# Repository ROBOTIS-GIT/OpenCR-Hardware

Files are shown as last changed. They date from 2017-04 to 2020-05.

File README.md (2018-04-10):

# OpenCR: Open Source Control Module for ROS
OpenCR (Open-source Control Module for ROS) is developed for ROS embedded systems to provide completely open-source hardware and software. 



# OpenCR-Hardware
Everything about the board; Schematics, PCB Gerber, BOM and the firmware source code for the TurtleBot3 and OP3 are free to distribute under open-source licenses for users and the ROS community. The STM32F7 series chip inside the OpenCR1.0 board is based on a very powerful ARM Cortex-M7 with floating point unit. The development environment for OpenCR1.0 is wide open from Arduino IDE and Scratch for young students to traditional firmware development for the expert.

## ROBOTIS e-Manual for OpenCR
- [ROBOTIS e-Manual for OpenCR](http://emanual.robotis.com/docs/en/parts/controller/opencr10/)

## Open Source related to OpenCR
- [OpenCR](https://github.com/ROBOTIS-GIT/OpenCR)
- [OpenCR-Hardware](https://github.com/ROBOTIS-GIT/OpenCR-Hardware)
- [OpenCM 9.04](https://github.com/ROBOTIS-GIT/OpenCM9.04)
- [dynamixel_sdk](https://github.com/ROBOTIS-GIT/DynamixelSDK)
- [dynamixel_workbench](https://github.com/ROBOTIS-GIT/dynamixel-workbench)
- [turtlebot3](https://github.com/ROBOTIS-GIT/turtlebot3)
- [open_manipulator](https://github.com/ROBOTIS-GIT/open_manipulator)
- [robotis_op3](https://github.com/ROBOTIS-GIT/ROBOTIS-OP3)

## Documents and Videos related to OpenCR
- [ROBOTIS e-Manual for OpenCR](http://emanual.robotis.com/docs/en/parts/controller/opencr10/)
- [ROBOTIS e-Manual for OpenCM 9.04](http://emanual.robotis.com/docs/en/parts/controller/opencm904/)
- [ROBOTIS e-Manual for OpenCM 485 Expansion Board](http://emanual.robotis.com/docs/en/parts/controller/opencm485exp/)
- [ROBOTIS e-Manual for Dynamixel SDK](http://emanual.robotis.com/docs/en/software/dynamixel/dynamixel_sdk/overview/)
- [ROBOTIS e-Manual for Dynamixel Workbench](http://emanual.robotis.com/docs/en/software/dynamixel/dynamixel_workbench/)
- [ROBOTIS e-Manual for TurtleBot3](http://turtlebot3.robotis.com/)
- [ROBOTIS e-Manual for OpenManipulator](http://emanual.robotis.com/docs/en/platform/openmanipulator/)
- [ROBOTIS e-Manual for ROBOTIS OP3](http://emanual.robotis.com/docs/en/platform/op3/introduction/)
- [Videos for OpenCR](https://www.youtube.com/playlist?list=PLRG6WP3c31_VTd-u90LVXaT1B8NMjCSoj)

## Tools for Hardware of OpenCR
- Schematic
  - OrCAD Capture 16.6

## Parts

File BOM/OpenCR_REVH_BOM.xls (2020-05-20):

BoardName | OpenCR
REV | H
Part Name | Reference | Quantity
C1608-1uF-16V | C2,C4,C5,C11,C70,C74,C100,C102,C103,C104,C105 | 11
C1608-NC | C6 | 1
C1005-0.1uF-35V | C7,C12,C13,C15,C16,C17,C18,C19,C20,C23,C24,C25,C26,C27,C28,C29,C30,C31,C32,C33,C35,C37,C44,C45,C46,C47,C51,C52,C55,C56,C61,C62,C66,C67,C71,C75,C79,C80,C81,C83,C84,C90,C94,C95,C96,C97,C99,C101,C106,C107,C108,C109,C110,C111,C112 | 55
C2012-4.7uF-16V | C14,C50,C69 | 3
C3216-10uF-25V | C21,C43,C59,C63,C22,C42,C48,C77 | 8
C1005-100pF-25V | C49,C57,C85 | 3
C1005-10nF-25V | C53 | 1
C1608-2.2uF-10V | C54,C82 | 2
C1005-9pF-25V | C58,C60 | 2
C3216-1uF-50V | C64,C87,C93,C98 | 4
C1005-8pF-25V | C65,C68 | 2
C2012-220nF-50V | C72 | 1
C2012-4.7nF/100V | C78 | 1
C1005-22nF-25V | C86 | 1
C1005-8.2nF-16V | C88 | 1
C1005-150pF-50V | C89 | 1
C1005-47pF-50V | C91 | 1
LED1608-ORANGE | D1,D2,D11 | 3
LED1608-RED | D3 | 1
LED1608-GREEN | D4,D5,D6,D7,D12 | 5
SS14-T3 (1N5819 SMA) | D9,D10,D22,D23 | 4
SK24 | D13 | 1
SK34C | D14,D17,D18,D19,D20,D21 | 6
SD24C | D15 | 1
SK56B | D16 | 1
BXJ(D10/L10), 470uF, 25V | EC1,EC3 | 2
BXJ(D5/L5.3), 22uF, 25V | EC2,EC4,EC5 | 3
BXJ(D8/L10), 68uF, 50V | EC6,EC7 | 2
BLM18PG121SN1 | FB1,FB4,FB6 | 3
FCM1608KF-601T03 | FB3,FB5 | 2
MF-MSMF200-2 | F1 | 1
Fuse_154010_DR(125V10A)_SMD | F2 | 1
FEMALE-10_2.54 | JP1 | 1
FEMALE-8_2.54 | JP2,JP3 | 2
FEMALE-6_2.54 | JP4 | 1
HEADER 5X2 1.27MM | J1 | 1
HEADER 10X2 2.54MM | J3 | 1
20010WS-02 | J5 | 1
20010WS-04 | J6,J8,J25 | 3
Molex 5267-02 | J7 | 1
SMW250-02 | J9,J10 | 2
ZX62D-B-5P8 | J11 | 1
DC JACK | J12 | 1
HEADER 1X2 2.0MM | J13 | 1
DEANS CONNECTOR (MALE) | J14 | 1
B3B-EH-A | J15,J16,J17 | 3
B4B-EH-A | J18,J19,J20 | 3
HEADER 3X2 2.54MM | J21 | 1
HEADER 5X2 2.0MM | J22,J24 | 2
Molex 53047-0210 | J23 | 1
BTN-0327 | LS1 | 1
33uH, 4A, | L1 | 1
XAL6060-472MEB | L2 | 1
CSD17577Q3A | Q5,Q7 | 2
CSD17302Q5A | Q6 | 1
CSD18537NQ5A | Q8 | 1
IRF4905SPbF | Q9 | 1
KRC106S | Q10,Q13,Q14 | 3
MMBT2222A/SOT | Q29 | 1
MMBT2907A/SOT | Q30 | 1
QM3016AD | Q31 | 1
R1005-470R | R1,R2,R3,R4,R5,R6,R7 | 7
R1005-10K | R8,R9,R10,R11,R36,R42,R50,R51,R55,R56,R57,R62,R64,R65,R66,R71,R73,R77,R78,R94,R97,R103,R104,R118,R120,R121,R124,R131,R132,R133,R135,R159,R162,R165,R167,R168,R170,R171,R173,R174,R176 | 41
R1005-10R | R12,R13,R14,R15,R16,R17,R18,R19,R20,R21,R22,R23,R24,R25,R26,R27,R28,R29 | 18
0.5 | R163,R164,R177,R178 | 4
R1608-0R | R34,R111,R119 | 3
R1005-22R | R37,R38,R160,R161 | 4
R1005-0R | R41,R44,R47,R48,R49,R52,R53,R54,R61,R63,R68,R70,R72,R91,R98,R102,R105,R108,R109 | 19
R1005-47K | R43,R134,R136,R137 | 4
R1005-620R | R45 | 1
R1005-330R | R46 | 1
R6432-0.01R | R58 | 1
R1608-100R | R59,R60 | 2
R1005-NC | R67,R69,R100,R106,R166,R169,R172,R175 | 8
R3216-120R | R74 | 1
R1608-10R | R75,R76,R110 | 3
R1005-10.5K | R90 | 1
R1005-2K | R92 | 1
R1005-100R | R93 | 1
R1005-2.7K | R95,R96,R179,R180 | 4
R1005-60.4R | R99,R101 | 2
R1005-63.4K | R112,R115,R117 | 3
R1608-10M | R113 | 1
R1608-93.1K | R116 | 1
R1005-5.36K | R122 | 1
R1608-280K | R126 | 1
R1608-20K | R127,R129 | 2
R1005-100K | R153,R154,R155,R156 | 4
R1005-22K | R157 | 1
SHK-02 | SW1 | 1
5MS1S12AM6QE | SW2 | 1
ST-1185S | SW3,SW4,SW5 | 3
DJTA-1101 | SW6 | 1
SM712 | U2,U12,U23 | 3
SQS401EN | U3 | 1
XL4005 | U4 | 1
STMPS2141STR | U5 | 1
STM32F746ZGT6 | U6 | 1
IL1117-5.0ET | U7,U14 | 2
ADM6713RAKS | U8 | 1
MPU-9250 | U9 | 1
AZ1117H-3_3TRG1 (SOT-223) | U10,U13 | 2
TJF1051T/3 | U11 | 1
EMIF02-USB03F2 | U16 | 1
LM5175PWPR | U17 | 1
LMV358IDGKR | U18 | 1
NC7WZ241K8X | U20 | 1
MAX3443ECSA+ | U21 | 1
NC7SZ08P5X | U22 | 1
A3906SESTR-T, QFN20 | U24,U25 | 2
X-Tal-32.768kHz_CM315 (CS-3215) | Y1 | 1
X-Tal-25MHz_SP8150E7 (SX-32) | Y2 | 1
R1608-47R | R181 | 1

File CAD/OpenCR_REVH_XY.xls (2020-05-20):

RefDes | PartDecal | Pins | Layer | Orient. | X | Y | SMD | Glued
C2 | ORC-CC1608 | 2 | Top | 180 | 83.42900067 | 68.56999933 | TRUE | FALSE
C4 | ORC-CC1608 | 2 | Top | 270 | 50.79999867 | 66.21099933 | TRUE | FALSE
C5 | ORC-CC1608 | 2 | Top | 270 | 52.399998 | 66.21099933 | TRUE | FALSE
C6 | ORC-CC1608 | 2 | Top | 180 | 50.31009867 | 63.308798 | TRUE | FALSE
C7 | ORC-CC1005 | 2 | Top | 90 | 98.05 | 62.4 | TRUE | FALSE
C11 | ORC-CC1608 | 2 | Bottom | 180 | 27.25 | 47.25 | TRUE | FALSE
C12 | ORC-CC1005 | 2 | Bottom | 0 | 27 | 48.75 | TRUE | FALSE
C13 | ORC-CC1005 | 2 | Bottom | 270 | 5.75 | 46.5 | TRUE | FALSE
C14 | ORC-CC2012 | 2 | Top | 180 | 94.4088 | 42.28989867 | TRUE | FALSE
C15 | ORC-CC1005 | 2 | Top | 180 | 101.108798 | 28.63989867 | TRUE | FALSE
C16 | ORC-CC1005 | 2 | Top | 180 | 96.80879933 | 28.58989867 | TRUE | FALSE
C17 | ORC-CC1005 | 2 | Top | 180 | 103.1087993 | 20.089898 | TRUE | FALSE
C18 | ORC-CC1005 | 2 | Top | 90 | 49.65 | 38 | TRUE | FALSE
C19 | ORC-CC1005 | 2 | Top | 270 | 51.71350067 | 40.825 | TRUE | FALSE
C20 | ORC-CC1005 | 2 | Top | 270 | 53.9135 | 40.8 | TRUE | FALSE
C21 | ORC-CC3216 | 2 | Top | 0 | 73.899998 | 15.29999867 | TRUE | FALSE
C22 | ORC-CC3216 | 2 | Top | 180 | 78.899998 | 15.29999867 | TRUE | FALSE
C23 | ORC-CC1005 | 2 | Top | 90 | 81.89999467 | 15.09999933 | TRUE | FALSE
C24 | ORC-CC1005 | 2 | Top | 270 | 61.75 | 14.75 | TRUE | FALSE
C25 | ORC-CC1005 | 2 | Top | 180 | 61.45879867 | 9.6 | TRUE | FALSE
C26 | ORC-CC1005 | 2 | Top | 0 | 67.499998 | 9.6 | TRUE | FALSE
C27 | ORC-CC1005 | 2 | Top | 180 | 53.83879867 | 9.499997333 | TRUE | FALSE
C28 | ORC-CC1005 | 2 | Top | 0 | 39.94149867 | 5.587998667 | TRUE | FALSE
C29 | ORC-CC1005 | 2 | Top | 180 | 31.3588 | 5.164898667 | TRUE | FALSE
C30 | ORC-CC1005 | 2 | Top | 0 | 50.99049867 | 5.524498667 | TRUE | FALSE
C31 | ORC-CC1005 | 2 | Top | 0 | 61.3588 | 5.5245 | TRUE | FALSE
C32 | ORC-CC1005 | 2 | Top | 0 | 75.0088 | 5.039898667 | TRUE | FALSE
C33 | ORC-CC1005 | 2 | Top | 0 | 88.14999733 | 5.499998 | TRUE | FALSE
C35 | ORC-CC1005 | 2 | Bottom | 0 | 8.5 | 64.75 | TRUE | FALSE
C37 | ORC-CC1005 | 2 | Bottom | 0 | 8.5 | 66 | TRUE | FALSE
C42 | ORC-CC3216 | 2 | Bottom | 180 | 58.95 | 53.9 | TRUE | FALSE
C43 | ORC-CC3216 | 2 | Bottom | 180 | 48.35879733 | 56.18989933 | TRUE | FALSE
C44 | ORC-CC1005 | 2 | Bottom | 0 | 58.29299867 | 55.81649867 | TRUE | FALSE
C45 | ORC-CC1005 | 2 | Bottom | 270 | 12.75 | 67.1 | TRUE | FALSE
C46 | ORC-CC1005 | 2 | Bottom | 270 | 75.14449867 | 51.62549867 | TRUE | FALSE
C47 | ORC-CC1005 | 2 | Bottom | 270 | 70.44549867 | 51.62549867 | TRUE | FALSE
C48 | ORC-CC3216 | 2 | Bottom | 90 | 5.3 | 64 | TRUE | FALSE
C49 | ORC-CC1005 | 2 | Bottom | 90 | 21.09119867 | 63.4601 | TRUE | FALSE
C50 | ORC-CC2012 | 2 | Bottom | 180 | 80.2 | 50.1388 | TRUE | FALSE
C51 | ORC-CC1005 | 2 | Bottom | 270 | 64.3088 | 52.63989867 | TRUE | FALSE
C52 | ORC-CC1005 | 2 | Bottom | 0 | 16 | 59.5 | TRUE | FALSE
C53 | ORC-CC1005 | 2 | Bottom | 180 | 20.59119867 | 64.7601 | TRUE | FALSE
C54 | ORC-CC1608 | 2 | Bottom | 180 | 80.2 | 48.4505 | TRUE | FALSE
C55 | ORC-CC1005 | 2 | Bottom | 270 | 5.5088 | 59.43989867 | TRUE | FALSE
C56 | ORC-CC1005 | 2 | Bottom | 270 | 65.2588 | 52.63989867 | TRUE | FALSE
C57 | ORC-CC1005 | 2 | Bottom | 90 | 21.1088 | 66.03989867 | TRUE | FALSE
C58 | ORC-CC1005 | 2 | Bottom | 270 | 67.442604 | 46.829798 | TRUE | FALSE
C59 | ORC-CC3216 | 2 | Bottom | 270 | 6.8588 | 52.93989867 | TRUE | FALSE
C60 | ORC-CC1005 | 2 | Bottom | 90 | 67.442604 | 44.72979733 | TRUE | FALSE
C61 | ORC-CC1005 | 2 | Bottom | 90 | 82.38349867 | 42.86249867 | TRUE | FALSE
C62 | ORC-CC1005 | 2 | Bottom | 0 | 64.85749867 | 41.52899867 | TRUE | FALSE
C63 | ORC-CC3216 | 2 | Bottom | 90 | 7.75 | 46.5 | TRUE | FALSE
C64 | ORC-CC3216 | 2 | Bottom | 90 | 24.6088 | 57.28989867 | TRUE | FALSE
C65 | ORC-CC1005 | 2 | Bottom | 270 | 67.4588 | 39.48989867 | TRUE | FALSE
C66 | ORC-CC1005 | 2 | Bottom | 270 | 33.25 | 34 | TRUE | FALSE
C67 | ORC-CC1005 | 2 | Bottom | 90 | 82.499998 | 37.55 | TRUE | FALSE
C68 | ORC-CC1005 | 2 | Bottom | 90 | 67.4588 | 37.389898 | TRUE | FALSE
C69 | ORC-CC2012 | 2 | Bottom | 0 | 65.6 | 36.45 | TRUE | FALSE
C70 | ORC-CC1608 | 2 | Bottom | 0 | 68.3088 | 34.68989867 | TRUE | FALSE
C71 | ORC-CC1005 | 2 | Bottom | 180 | 63.39999867 | 34.599998 | TRUE | FALSE
C72 | ORC-CC2012 | 2 | Bottom | 180 | 44.5 | 35.5 | TRUE | FALSE
C74 | ORC-CC1608 | 2 | Bottom | 0 | 68.3088 | 33.23829867 | TRUE | FALSE
C75 | ORC-CC1005 | 2 | Bottom | 180 | 63.39999867 | 33.19999867 | TRUE | FALSE
C77 | ORC-CC3216 | 2 | Bottom | 0 | 11.5 | 53.5 | TRUE | FALSE
C78 | ORC-CC2012 | 2 | Bottom | 270 | 97.950002 | 32.5 | TRUE | FALSE
C79 | ORC-CC1005 | 2 | Bottom | 180 | 75.90649867 | 30.79749867 | TRUE | FALSE
C80 | ORC-CC1005 | 2 | Bottom | 180 | 70.82649867 | 30.79749867 | TRUE | FALSE
C81 | ORC-CC1005 | 2 | Bottom | 180 | 65.91299867 | 30.79749867 | TRUE | FALSE
C82 | ORC-CC1608 | 2 | Bottom | 180 | 79.95 | 29.85 | TRUE | FALSE
C83 | ORC-CC1005 | 2 | Top | 270 | 35.75 | 31.5 | TRUE | FALSE
C84 | ORC-CC1005 | 2 | Bottom | 0 | 13.7 | 42.5 | TRUE | FALSE
C85 | ORC-CC1005 | 2 | Bottom | 0 | 45.5 | 29 | TRUE | FALSE
C86 | ORC-CC1005 | 2 | Bottom | 180 | 45.5 | 27.75 | TRUE | FALSE
C87 | ORC-CC3216 | 2 | Bottom | 270 | 23.5 | 26.5 | TRUE | FALSE
C88 | ORC-CC1005 | 2 | Bottom | 180 | 47.75 | 26.5 | TRUE | FALSE
C89 | ORC-CC1005 | 2 | Bottom | 180 | 45.5 | 25.5 | TRUE | FALSE
C90 | ORC-CC1005 | 2 | Bottom | 270 | 32.75 | 23 | TRUE | FALSE
C91 | ORC-CC1005 | 2 | Bottom | 0 | 35.25 | 23.25 | TRUE | FALSE
C93 | ORC-CC3216 | 2 | Top | 0 | 52.7 | 31.15 | TRUE | FALSE
C94 | ORC-CC1005 | 2 | Bottom | 90 | 77.35879733 | 17.239896 | TRUE | FALSE
C95 | ORC-CC1005 | 2 | Bottom | 90 | 71.875 | 15.75 | TRUE | FALSE
C96 | ORC-CC1005 | 2 | Bottom | 0 | 85.72499867 | 14.7 | TRUE | FALSE
C97 | ORC-CC1005 | 2 | Bottom | 0 | 36.14999733 | 11.949998 | TRUE | FALSE
C98 | ORC-CC3216 | 2 | Bottom | 180 | 40.424998 | 6.375 | TRUE | FALSE
C99 | ORC-CC1005 | 2 | Top | 180 | 15.1088 | 68.28989867 | TRUE | FALSE
C100 | ORC-CC1608 | 2 | Bottom | 0 | 64.8 | 48.6 | TRUE | FALSE
C101 | ORC-CC1005 | 2 | Bottom | 270 | 101 | 11.15 | TRUE | FALSE
C102 | ORC-CC1608 | 2 | Bottom | 0 | 97 | 64.25 | TRUE | FALSE
C103 | ORC-CC1608 | 2 | Bottom | 270 | 92 | 63.5 | TRUE | FALSE
C104 | ORC-CC1608 | 2 | Bottom | 180 | 94.25 | 64.25 | TRUE | FALSE
C105 | ORC-CC1608 | 2 | Bottom | 180 | 94.25 | 62.75 | TRUE | FALSE
C106 | ORC-CC1005 | 2 | Bottom | 180 | 100 | 52.25 | TRUE | FALSE
C107 | ORC-CC1005 | 2 | Top | 270 | 50.525 | 19.725 | TRUE | FALSE
C108 | ORC-CC1005 | 2 | Top | 270 | 50.525 | 21.6 | TRUE | FALSE
C109 | ORC-CC1005 | 2 | Top | 180 | 52.1 | 17.1 | TRUE | FALSE
C110 | ORC-CC1005 | 2 | Top | 270 | 60.025 | 19.725 | TRUE | FALSE
C111 | ORC-CC1005 | 2 | Top | 270 | 60.025 | 21.6 | TRUE | FALSE
C112 | ORC-CC1005 | 2 | Top | 90 | 60 | 17.8 | TRUE | FALSE
D1 | ORC-LED1608 | 2 | Top | 90 | 25.90879867 | 71.939898 | TRUE | FALSE
D2 | ORC-LED1608 | 2 | Top | 90 | 28.60879867 | 71.939898 | TRUE | FALSE
D3 | ORC-LED1608 | 2 | Top | 90 | 31.308798 | 71.939898 | TRUE | FALSE
D4 | ORC-LED1608 | 2 | Top | 90 | 34.008798 | 71.939898 | TRUE | FALSE
D5 | ORC-LED1608 | 2 | Top | 90 | 42.00879733 | 71.939898 | TRUE | FALSE
D6 | ORC-LED1608 | 2 | Top | 90 | 36.8088 | 71.939898 | TRUE | FALSE
D7 | ORC-LED1608 | 2 | Top | 90 | 39.50879933 | 71.939898 | TRUE | FALSE
D9 | ORC-SMA-SS14 | 2 | Top | 270 | 90.09999867 | 54.2 | TRUE | FALSE
D10 | ORC-SMA-SS14 | 2 | Top | 90 | 90.09999867 | 44.899998 | TRUE | FALSE
D11 | ORC-LED1608 | 2 | Top | 90 | 96.75879933 | 43.58989867 | TRUE | FALSE
D12 | ORC-LED1608 | 2 | Top | 90 | 99.45879867 | 43.58989867 | TRUE | FALSE
D13 | ORC-SMB-SS24 | 2 | Top | 270 | 25.5 | 22.5 | TRUE | FALSE
D14 | ORC-SMC-SS34 | 2 | Bottom | 90 | 21.75 | 34.5 | TRUE | FALSE
D15 | ORC-SOD323-TVS | 2 | Top | 0 | 57.4 | 5.65 | TRUE | FALSE
D16 | ORC-DO214AC | 2 | Top | 0 | 36.75 | 50.5 | TRUE | FALSE
D17 | ORC-SMC-SS34 | 2 | Bottom | 180 | 37.75 | 38.5 | TRUE | FALSE
D18 | ORC-SMC-SS34 | 2 | Bottom | 90 | 28.5 | 34.5 | TRUE | FALSE
D19 | ORC-SMC-SS34 | 2 | Bottom | 270 | 5 | 34 | TRUE | FALSE
D20 | ORC-SMC-SS34 | 2 | Bottom | 270 | 28.5 | 25.5 | TRUE | FALSE
D21 | ORC-SMC-SS34 | 2 | Bottom | 270 | 14.25 | 21 | TRUE | FALSE
D22 | ORC-SMA-SS14 | 2 | Bottom | 270 | 42.346 | 10.85 | TRUE | FALSE
D23 | ORC-SMA-SS14 | 2 | Bottom | 270 | 38.994 | 10.85 | TRUE | FALSE
EC1 | ORC-ACAP-D10XL0 | 2 | Top | 180 | 13.5 | 61 | TRUE | FALSE
EC2 | ORC-ACAP-D5XL5_3 | 2 | Top | 90 | 44 | 21.75 | TRUE | FALSE
EC4 | ORC-ACAP-D5XL5_3 | 2 | Top | 90 | 44 | 33.25 | TRUE | FALSE
EC5 | ORC-ACAP-D5XL5_3 | 2 | Top | 90 | 44 | 27.5 | TRUE | FALSE
EC6 | ORC-ACAP-D8XL0 | 2 | Top | 0 | 17 | 23.5 | TRUE | FALSE
EC7 | ORC-ACAP-D8XL0 | 2 | Top | 90 | 17 | 13 | TRUE | FALSE
EC8 | ORC-ACAP-D10XL0 | 2 | Top | 180 | 13.5 | 48.5 | TRUE | FALSE
F1 | ORC-FC4532 | 2 | Top | 270 | 94.75 | 36.0649 | TRUE | FALSE
F2 | FUSE/0154005.DRT(125V5A) | 2 | Bottom | 90 | 8 | 21.5 | TRUE | FALSE
FB1 | ORC-LC1608 | 2 | Top | 180 | 92.9088 | 40.23989867 | TRUE | FALSE
FB3 | ORC-LC1608 | 2 | Bottom | 270 | 67.9588 | 30.53989933 | TRUE | FALSE
FB4 | ORC-LC1608 | 2 | Bottom | 0 | 77.15 | 27.25 | TRUE | FALSE
FB5 | ORC-LC1608 | 2 | Top | 180 | 57.35 | 31.85 | TRUE | FALSE
FB6 | ORC-LC1608 | 2 | Bottom | 270 | 99.5 | 11.15 | TRUE | FALSE
J1 | ORC-HERDER2X5_P1_27 | 10 | Top | 180 | 80.505398 | 72.39999867 | FALSE | FALSE
J3 | ORC-HERDER2X10-P2_54 | 20 | Top | 0 | 62.73 | 71.43 | FALSE | FALSE
J5 | ORC-CON2-20010WS-02 | 2 | Top | 270 | 2.374998 | 64.44999667 | FALSE | FALSE
J6 | ORC-CON4-20010WS-04 | 4 | Top | 270 | 102.1999973 | 61.7 | FALSE | FALSE
J7 | 5267-02A-2.5P | 2 | Top | 270 | 3.262698667 | 55.7501 | FALSE | FALSE
J8 | ORC-CON4-20010WS-04 | 4 | Top | 0 | 15.3 | 72 | FALSE | FALSE
J9 | ORC-CON2-SMW250-02 | 2 | Top | 270 | 2.85 | 46.35 | FALSE | FALSE
J10 | ORC-CON2-SMW250-02 | 2 | Top | 270 | 2.85 | 22 | FALSE | FALSE
SB-B J11 | USB-ZX62D-B-5PA8+MICRO_US | B-B 11 | Top | 90 | 104.3 | 35.4524 | FALSE | FALSE
J12 | ORC-DCJACK | 3 | Top | 0 | 3.8 | 12.5 | FALSE | FALSE
J13 | ORC-HERDER1X2_P2_0 | 2 | Top | 270 | 92.7742 | 11.39999667 | FALSE | FALSE
J14 | DEANS_CONNECTOR(MALE) | 2 | Top | 270 | 16.875 | 4.25 | FALSE | FALSE
J15 | ORC-CON3-B3B-EH-A | 3 | Top | 0 | 30.29999933 | 2.599998667 | FALSE | FALSE
J16 | ORC-CON3-B3B-EH-A | 3 | Top | 0 | 40.999998 | 2.599998667 | FALSE | FALSE
J17 | ORC-CON3-B3B-EH-A | 3 | Top | 0 | 51.69999933 | 2.599998667 | FALSE | FALSE
J18 | ORC-CON4-B4B-EH-A | 4 | Top | 0 | 63.7001 | 2.598599333 | FALSE | FALSE
J19 | ORC-CON4-B4B-EH-A | 4 | Top | 0 | 76.90009867 | 2.598599333 | FALSE | FALSE
J20 | ORC-CON4-B4B-EH-A | 4 | Top | 0 | 90.100098 | 2.598599333 | FALSE | FALSE
J21 | ORC-HERDER2X3-P2_54 | 6 | Top | 270 | 86.49880467 | 39.719886 | FALSE | FALSE
J22 | ORC-HERDER2X5_P2_0 | 10 | Top | 180 | 90.9 | 71.9 | FALSE | FALSE
J23 | 53047-0210 | 2 | Top | 90 | 102.95 | 10 | FALSE | FALSE
J24 | ORC-HERDER2X5_P2_0 | 10 | Top | 180 | 90.9 | 67.9 | FALSE | FALSE
J25 | ORC-CON4-20010WS-04 | 4 | Top | 270 | 102.2 | 50.9 | FALSE | FALSE
JP1 | ORC-HERDER1X10-P2_54 | 10 | Top | 0 | 53.0848 | 60.08989867 | FALSE | FALSE
JP2 | ORC-HERDER1X8-P2_54 | 8 | Top | 0 | 77.4688 | 60.08989867 | FALSE | FALSE
JP3 | ORC-HERDER1X8-P2_54 | 8 | Top | 0 | 59.6888 | 11.82989867 | FALSE | FALSE
JP4 | ORC-HERDER1X6-P2_54 | 6 | Top | 0 | 80.0088 | 11.82989867 | FALSE | FALSE
L1 | ORC-IND-TSL1295 | 2 | Top | 180 | 26.6088 | 46.53989867 | TRUE | FALSE
L2 | ORC-IND6_4X6_6 | 2 | Top | 270 | 25.5 | 29.75 | TRUE | FALSE
LS1 | BUZZER(BMX-2703) | 2 | Top | 270 | 90.399998 | 23.04999867 | TRUE | FALSE
MT1 | NTH4.0 | 1 | Top | 0 | 4.5 | 4.5 | FALSE | FALSE
MT2 | NTH4.0 | 1 | Top | 0 | 100.499998 | 4.5 | FALSE | FALSE
MT3 | NTH4.0 | 1 | Top | 0 | 4.5 | 70.5 | FALSE | FALSE
MT4 | NTH4.0 | 1 | Top | 0 | 100.499998 | 70.5 | FALSE | FALSE
Q5 | ORC-SON8_3_3X3_3 | 8 | Top | 90 | 31.25 | 22.25 | TRUE | FALSE
Q6 | ORC-SON8_5X6 | 8 | Top | 0 | 25.25 | 37 | TRUE | FALSE
Q7 | ORC-SON8_3_3X3_3 | 8 | Top | 90 | 31.25 | 28.25 | TRUE | FALSE
Q8 | ORC-SON8_5X6 | 8 | Top | 270 | 32.5 | 35.75 | TRUE | FALSE
Q9 | ORC-D2PAK | 3 | Top | 270 | 39 | 12.55 | TRUE | FALSE
Q10 | ORC-SOT23 | 3 | Bottom | 180 | 42.29099867 | 72.23799733 | TRUE | FALSE
Q13 | ORC-SOT23 | 3 | Bottom | 90 | 94.5765 | 25.49999867 | TRUE | FALSE
Q14 | ORC-SOT23 | 3 | Bottom | 0 | 35.625 | 14.94999933 | TRUE | FALSE
Q29 | ORC-SOT23 | 3 | Bottom | 270 | 26.25 | 6 | TRUE | FALSE
Q30 | ORC-SOT23 | 3 | Bottom | 270 | 22.75 | 18.5 | TRUE | FALSE
Q31 | QM3016D(TO-252_H2.3) | 3 | Bottom | 270 | 27.25 | 11.25 | TRUE | FALSE
R1 | ORC-RC1005 | 2 | Top | 270 | 41.99999867 | 69.389898 | TRUE | FALSE
R2 | ORC-RC1005 | 2 | Top | 270 | 25.90879867 | 69.389898 | TRUE | FALSE
R3 | ORC-RC1005 | 2 | Top | 270 | 28.60879867 | 69.389898 | TRUE | FALSE
R4 | ORC-RC1005 | 2 | Top | 270 | 31.308798 | 69.389898 | TRUE | FALSE
R5 | ORC-RC1005 | 2 | Top | 270 | 34.008798 | 69.389898 | TRUE | FALSE
R6 | ORC-RC1005 | 2 | Top | 270 | 36.8088 | 69.439898 | TRUE | FALSE
R7 | ORC-RC1005 | 2 | Top | 270 | 39.50879933 | 69.389898 | TRUE | FALSE
R8 | ORC-RC1005 | 2 | Top | 180 | 83.62900067 | 69.96999933 | TRUE | FALSE
R9 | ORC-RC1005 | 2 | Top | 270 | 81.429 | 69.47 | TRUE | FALSE
R10 | ORC-RC1005 | 2 | Top | 90 | 80.38780067 | 69.45990133 | TRUE | FALSE
R11 | ORC-RC1005 | 2 | Top | 90 | 79.15 | 69.45 | TRUE | FALSE
R12 | ORC-RC1005 | 2 | Top | 90 | 53.799998 | 66.7 | TRUE | FALSE
R13 | ORC-RC1005 | 2 | Top | 270 | 55.099998 | 66.7 | TRUE | FALSE
R14 | ORC-RC1005 | 2 | Top | 90 | 56.299998 | 66.7 | TRUE | FALSE
R15 | ORC-RC1005 | 2 | Top | 270 | 57.49999533 | 66.7 | TRUE | FALSE
R16 | ORC-RC1005 | 2 | Top | 90 | 58.799998 | 66.7 | TRUE | FALSE
R17 | ORC-RC1005 | 2 | Top | 270 | 59.999998 | 66.7 | TRUE | FALSE
R18 | ORC-RC1005 | 2 | Top | 90 | 61.299998 | 66.7 | TRUE | FALSE
R19 | ORC-RC1005 | 2 | Top | 270 | 62.499998 | 66.7 | TRUE | FALSE
R20 | ORC-RC1005 | 2 | Top | 90 | 63.799998 | 66.7 | TRUE | FALSE
R21 | ORC-RC1005 | 2 | Top | 270 | 65.099998 | 66.7 | TRUE | FALSE
R22 | ORC-RC1005 | 2 | Top | 90 | 66.299998 | 66.7 | TRUE | FALSE
R23 | ORC-RC1005 | 2 | Top | 270 | 67.599998 | 66.7 | TRUE | FALSE
R24 | ORC-RC1005 | 2 | Top | 90 | 68.799998 | 66.7 | TRUE | FALSE
R25 | ORC-RC1005 | 2 | Top | 270 | 70.099998 | 66.7 | TRUE | FALSE
R26 | ORC-RC1005 | 2 | Top | 90 | 71.299998 | 66.7 | TRUE | FALSE
R27 | ORC-RC1005 | 2 | Top | 270 | 72.49999867 | 66.7 | TRUE | FALSE
R28 | ORC-RC1005 | 2 | Top | 90 | 73.79999867 | 66.7 | TRUE | FALSE
R29 | ORC-RC1005 | 2 | Top | 270 | 75.099998 | 66.7 | TRUE | FALSE
R34 | ORC-RC1608 | 2 | Top | 180 | 47.41009933 | 63.308798 | TRUE | FALSE
R36 | ORC-RC1005 | 2 | Top | 90 | 96.85 | 62.4 | TRUE | FALSE
R37 | ORC-RC1005 | 2 | Top | 90 | 98.099998 | 60.19999533 | TRUE | FALSE
R38 | ORC-RC1005 | 2 | Top | 270 | 98.099998 | 57.19999867 | TRUE | FALSE
R41 | ORC-RC1005 | 2 | Top | 270 | 96.75879933 | 51.03989933 | TRUE | FALSE
R42 | ORC-RC1005 | 2 | Top | 270 | 96.75879933 | 48.68989867 | TRUE | FALSE
R43 | ORC-RC1005 | 2 | Top | 90 | 96.75879933 | 46.589898 | TRUE | FALSE
R44 | ORC-RC1005 | 2 | Top | 90 | 97.85879933 | 46.589898 | TRUE | FALSE
R45 | ORC-RC1005 | 2 | Top | 0 | 97.25 | 41.24999733 | TRUE | FALSE
R46 | ORC-RC1005 | 2 | Top | 0 | 99.94999933 | 41.24999733 | TRUE | FALSE
R47 | ORC-RC1005 | 2 | Top | 270 | 97.85879933 | 38.16489867 | TRUE | FALSE
R48 | ORC-RC1005 | 2 | Top | 0 | 98 | 35.75 | TRUE | FALSE
R49 | ORC-RC1005 | 2 | Top | 0 | 98 | 34.65 | TRUE | FALSE
R50 | ORC-RC1005 | 2 | Top | 270 | 102.608798 | 28.13989933 | TRUE | FALSE
R51 | ORC-RC1005 | 2 | Top | 270 | 98.35879867 | 28.08989667 | TRUE | FALSE
R52 | ORC-RC1005 | 2 | Top | 180 | 59.75 | 30.25 | TRUE | FALSE
R53 | ORC-RC1005 | 2 | Top | 180 | 59.75 | 29 | TRUE | FALSE
R54 | ORC-RC1005 | 2 | Top | 90 | 52.8135 | 40.8 | TRUE | FALSE
R55 | ORC-RC1005 | 2 | Top | 180 | 52.3 | 42.65 | TRUE | FALSE
R56 | ORC-RC1005 | 2 | Top | 180 | 101.108798 | 27.639898 | TRUE | FALSE
R57 | ORC-RC1005 | 2 | Top | 180 | 96.80879933 | 27.589898 | TRUE | FALSE
R58 | ORC-RC6432 | 2 | Bottom | 270 | 20 | 25.75 | TRUE | FALSE
R59 | ORC-RC1608 | 2 | Bottom | 270 | 34.5 | 21 | TRUE | FALSE
R60 | ORC-RC1608 | 2 | Bottom | 270 | 36.25 | 21 | TRUE | FALSE
R61 | ORC-RC1005 | 2 | Top | 180 | 50.12840067 | 41.51620067 | TRUE | FALSE
R62 | ORC-RC1005 | 2 | Top | 180 | 50.1385 | 40.32499867 | TRUE | FALSE
R63 | ORC-RC1005 | 2 | Top | 270 | 51.75 | 34 | TRUE | FALSE
R64 | ORC-RC1005 | 2 | Top | 270 | 52.75 | 34 | TRUE | FALSE
R65 | ORC-RC1005 | 2 | Top | 270 | 53.75 | 34 | TRUE | FALSE
R66 | ORC-RC1005 | 2 | Top | 90 | 60.65 | 14.75 | TRUE | FALSE
R67 | ORC-RC1005 | 2 | Top | 90 | 82.90879933 | 15.0899 | TRUE | FALSE
R68 | ORC-RC1005 | 2 | Top | 90 | 83.8588 | 15.0899 | TRUE | FALSE
R69 | ORC-RC1005 | 2 | Top | 90 | 85.40879933 | 15.0899 | TRUE | FALSE
R70 | ORC-RC1005 | 2 | Top | 90 | 86.3588 | 15.0899 | TRUE | FALSE
R71 | ORC-RC1005 | 2 | Top | 180 | 55.15 | 14.05 | TRUE | FALSE
R72 | ORC-RC1005 | 2 | Top | 270 | 54.75 | 34 | TRUE | FALSE
R73 | ORC-RC1005 | 2 | Top | 180 | 95 | 16.25 | TRUE | FALSE
R74 | R3216 | 2 | Top | 270 | 91.15 | 11.45 | TRUE | FALSE
R75 | ORC-RC1608 | 2 | Top | 270 | 91.14999933 | 6.499998667 | TRUE | FALSE
R76 | ORC-RC1608 | 2 | Top | 270 | 93.64999933 | 6.499998667 | TRUE | FALSE
R77 | ORC-RC1005 | 2 | Bottom | 90 | 46.54549867 | 69.21499867 | TRUE | FALSE
R78 | ORC-RC1005 | 2 | Bottom | 90 | 45.27549867 | 69.21499867 | TRUE | FALSE
R90 | ORC-RC1005 | 2 | Bottom | 90 | 20.8588 | 59.78989867 | TRUE | FALSE
R91 | ORC-RC1005 | 2 | Bottom | 180 | 20.3588 | 58.28989867 | TRUE | FALSE
R92 | ORC-RC1005 | 2 | Bottom | 270 | 19.8588 | 59.78989867 | TRUE | FALSE
R93 | ORC-RC1005 | 2 | Bottom | 180 | 80.1588 | 52.53989867 | TRUE | FALSE
R94 | ORC-RC1005 | 2 | Bottom | 90 | 12.75 | 62.8 | TRUE | FALSE
R95 | ORC-RC1005 | 2 | Bottom | 90 | 67.9088 | 51.58989867 | TRUE | FALSE
R96 | ORC-RC1005 | 2 | Bottom | 90 | 66.9588 | 51.58989867 | TRUE | FALSE
R97 | ORC-RC1005 | 2 | Bottom | 270 | 66.0588 | 51.58989867 | TRUE | FALSE
R98 | ORC-RC1005 | 2 | Bottom | 270 | 68.8588 | 51.58989867 | TRUE | FALSE
R99 | ORC-RC1005 | 2 | Bottom | 90 | 20.09119867 | 63.4601 | TRUE | FALSE
R100 | ORC-RC1005 | 2 | Bottom | 0 | 65 | 49.75 | TRUE | FALSE
R101 | ORC-RC1005 | 2 | Bottom | 270 | 20.1088 | 66.03989867 | TRUE | FALSE
R102 | ORC-RC1005 | 2 | Bottom | 0 | 66.1088 | 46.33989667 | TRUE | FALSE
R103 | ORC-RC1005 | 2 | Bottom | 90 | 82.38349867 | 45.52949867 | TRUE | FALSE
R104 | ORC-RC1005 | 2 | Bottom | 90 | 20.1088 | 67.78989867 | TRUE | FALSE
R105 | ORC-RC1005 | 2 | Bottom | 0 | 66.1088 | 45.23989867 | TRUE | FALSE
R106 | ORC-RC1005 | 2 | Bottom | 90 | 21.1088 | 67.78989867 | TRUE | FALSE
R108 | ORC-RC1005 | 2 | Bottom | 0 | 66.09999867 | 38.99999933 | TRUE | FALSE
R109 | ORC-RC1005 | 2 | Bottom | 0 | 66.09999867 | 37.89999933 | TRUE | FALSE
R110 | ORC-RC1608 | 2 | Bottom | 90 | 43.7 | 38 | TRUE | FALSE
R111 | ORC-RC1608 | 2 | Bottom | 270 | 66.199998 | 33.89999933 | TRUE | FALSE
R112 | ORC-RC1005 | 2 | Top | 180 | 42.5 | 37 | TRUE | FALSE
R113 | ORC-RC1608 | 2 | Bottom | 270 | 96.25 | 32.5 | TRUE | FALSE
R115 | ORC-RC1005 | 2 | Top | 180 | 42.5 | 38 | TRUE | FALSE
R116 | ORC-RC1608 | 2 | Bottom | 180 | 45.5 | 31.75 | TRUE | FALSE
R117 | ORC-RC1005 | 2 | Bottom | 0 | 45.5 | 30.25 | TRUE | FALSE
R118 | ORC-RC1005 | 2 | Bottom | 270 | 19.5 | 43.25 | TRUE | FALSE
R119 | ORC-RC1608 | 2 | Bottom | 180 | 43 | 21 | TRUE | FALSE
R120 | ORC-RC1005 | 2 | Bottom | 270 | 20.75 | 43.25 | TRUE | FALSE
R121 | ORC-RC1005 | 2 | Bottom | 270 | 18.25 | 43.25 | TRUE | FALSE
R122 | ORC-RC1005 | 2 | Bottom | 0 | 45.5 | 26.5 | TRUE | FALSE
R124 | ORC-RC1005 | 2 | Bottom | 270 | 21.1088 | 46.78989867 | TRUE | FALSE
R126 | ORC-RC1608 | 2 | Bottom | 90 | 43.75 | 23.25 | TRUE | FALSE
R127 | ORC-RC1608 | 2 | Bottom | 90 | 45.5 | 23.25 | TRUE | FALSE
R129 | ORC-RC1608 | 2 | Top | 90 | 35.5 | 28.5 | TRUE | FALSE
R131 | ORC-RC1005 | 2 | Bottom | 90 | 72.95879867 | 18.73989533 | TRUE | FALSE
R132 | ORC-RC1005 | 2 | Bottom | 180 | 75.45879867 | 17.7399 | TRUE | FALSE
R133 | ORC-RC1005 | 2 | Top | 0 | 49 | 32.75 | TRUE | FALSE
R134 | ORC-RC1005 | 2 | Top | 180 | 49 | 33.75 | TRUE | FALSE
R135 | ORC-RC1005 | 2 | Bottom | 0 | 80.7 | 14.7 | TRUE | FALSE
R136 | ORC-RC1005 | 2 | Bottom | 270 | 44.95 | 10.85 | TRUE | FALSE
R137 | ORC-RC1005 | 2 | Bottom | 270 | 35.64999867 | 10.12499733 | TRUE | FALSE
R153 | ORC-RC1005 | 2 | Bottom | 0 | 11.75 | 8.25 | TRUE | FALSE
R154 | ORC-RC1005 | 2 | Bottom | 270 | 23.5 | 4.5 | TRUE | FALSE
R155 | ORC-RC1005 | 2 | Bottom | 180 | 22 | 16 | TRUE | FALSE
R156 | ORC-RC1005 | 2 | Bottom | 0 | 24.5 | 16 | TRUE | FALSE
R157 | ORC-RC1005 | 2 | Bottom | 180 | 27 | 16 | TRUE | FALSE
R159 | ORC-RC1005 | 2 | Bottom | 180 | 100 | 51.25 | TRUE | FALSE
R160 | ORC-RC1005 | 2 | Bottom | 0 | 100 | 50 | TRUE | FALSE
R161 | ORC-RC1005 | 2 | Bottom | 0 | 100 | 48 | TRUE | FALSE
R162 | ORC-RC1005 | 2 | Top | 270 | 53.925 | 16.35 | TRUE | FALSE
R163 | R2012 | 2 | Top | 270 | 65.525 | 25.05 | TRUE | FALSE
R164 | R2012 | 2 | Top | 90 | 61.525 | 25.05 | TRUE | FALSE
R165 | ORC-RC1005 | 2 | Top | 90 | 57.375 | 20.25 | TRUE | FALSE
R166 | ORC-RC1005 | 2 | Top | 0 | 92.4 | 61.75 | TRUE | FALSE
R167 | ORC-RC1005 | 2 | Top | 270 | 57.375 | 18.4 | TRUE | FALSE
R168 | ORC-RC1005 | 2 | Top | 270 | 55.125 | 16.375 | TRUE | FALSE
R169 | ORC-RC1005 | 2 | Top | 0 | 92.4 | 62.8 | TRUE | FALSE
R170 | ORC-RC1005 | 2 | Top | 90 | 84.65 | 45.25 | TRUE | FALSE
R171 | ORC-RC1005 | 2 | Top | 270 | 64 | 16.35 | TRUE | FALSE
R172 | ORC-RC1005 | 2 | Top | 0 | 92.4 | 63.85 | TRUE | FALSE
R173 | ORC-RC1005 | 2 | Top | 270 | 65.125 | 16.375 | TRUE | FALSE
R174 | ORC-RC1005 | 2 | Top | 270 | 67.125 | 18.5 | TRUE | FALSE
R175 | ORC-RC1005 | 2 | Top | 0 | 92.4 | 64.95 | TRUE | FALSE
R176 | ORC-RC1005 | 2 | Top | 90 | 67.125 | 20.625 | TRUE | FALSE
R177 | R2012 | 2 | Top | 90 | 52.025 | 25.05 | TRUE | FALSE
R178 | R2012 | 2 | Top | 270 | 56.025 | 25.05 | TRUE | FALSE
R179 | ORC-RC1005 | 2 | Bottom | 270 | 36.55 | 18.05 | TRUE | FALSE
R180 | ORC-RC1005 | 2 | Bottom | 270 | 34.65 | 18.05 | TRUE | FALSE
R181 | ORC-RC1608 | 2 | Top | 180 | 53.95 | 5.65 | TRUE | FALSE
SW1 | ORC-SW-SHK-02 | 4 | Top | 0 | 45.88499933 | 70.04889867 | TRUE | FALSE
SW2 | ORC-SW3_SPDT | 5 | Top | 270 | 4.6 | 34 | FALSE | FALSE
SW3 | ORC-SW2_ST-1185S | 2 | Top | 270 | 98.34999733 | 24.17399933 | TRUE | FALSE
SW4 | ORC-SW2_ST-1185S | 2 | Top | 270 | 102.5999993 | 24.17399933 | TRUE | FALSE
SW5 | ORC-SW2_ST-1185S | 2 | Top | 270 | 102.5999993 | 16.17399733 | TRUE | FALSE
SW6 | ORC-SW2_DATA-1101 | 2 | Top | 90 | 98.558798 | 14.939898 | TRUE | FALSE
U2 | ORC-SOT23 | 3 | Top | 90 | 95.375 | 58.699998 | TRUE | FALSE
U3 | ORC-SON8_3_3X3_3_1212-8 | 8 | Top | 90 | 94.35879933 | 51.489896 | TRUE | FALSE
U4 | ORC-TO263-5L | 6 | Top | 270 | 31.3588 | 59.28989867 | TRUE | FALSE
U5 | ORC-SOT23-5P | 5 | Top | 0 | 94.5088 | 45.33989867 | TRUE | FALSE
U6 | ORC-QFP144-P0_5-W22X22 | 144 | Top | 270 | 72.399998 | 40.899996 | TRUE | FALSE
U7 | ORC-SOT223 | 4 | Top | 90 | 75.399998 | 20.49999867 | TRUE | FALSE
U8 | ORC-SC82CR-SC70_4P | 4 | Top | 270 | 58 | 14.75 | TRUE | FALSE
U9 | ORC-QFN24-P0_4-W3X3 | 25 | Top | 90 | 52.5 | 37.5 | TRUE | FALSE
U10 | ORC-SOT223 | 4 | Bottom | 270 | 49.85879933 | 50.98989667 | TRUE | FALSE
U11 | ORC-SOP8_P127_W6 | 8 | Bottom | 180 | 16.14119867 | 63.8601 | TRUE | FALSE
U12 | ORC-SOT23 | 3 | Bottom | 270 | 21.56619933 | 71.4601 | TRUE | FALSE
U13 | ORC-SOT223 | 4 | Bottom | 180 | 9.5 | 59.5 | TRUE | FALSE
U14 | ORC-SOT223 | 4 | Bottom | 180 | 13 | 47.75 | TRUE | FALSE
U16 | BGA11-P0_5-W1_44X1_94 | 11 | Bottom | 180 | 98.15 | 35.65 | TRUE | FALSE
U17 | ORC-SOP28-P0_65-W5_6-HT | 29 | Bottom | 90 | 38.5 | 29.5 | TRUE | FALSE
U18 | ORC-SOP8-P0_65-W4_4 | 8 | Bottom | 0 | 18.5 | 47.75 | TRUE | FALSE
U20 | ORC-SOP8_P0_5-W2_7 | 8 | Bottom | 270 | 75.958798 | 19.53989867 | TRUE | FALSE
U21 | ORC-SO8 | 8 | Bottom | 270 | 82.41129933 | 18.46739933 | TRUE | FALSE
U22 | NC7SZ08P5X(SOT-23) | 5 | Bottom | 270 | 74.5 | 15.25 | TRUE | FALSE
U23 | ORC-SOT23 | 3 | Bottom | 90 | 96.5 | 49 | TRUE | FALSE
U24 | QFN20-0.5-4.0X4.0(A3906) | 21 | Top | 0 | 54.025 | 20.35 | TRUE | FALSE
U25 | QFN20-0.5-4.0X4.0(A3906) | 21 | Top | 0 | 63.525 | 20.35 | TRUE | FALSE
Y1 | ORC-XTAL_SMD2-3215 | 2 | Bottom | 270 | 68.9088 | 45.73989867 | TRUE | FALSE
Y2 | ORC-XTAL4_3225 | 4 | Bottom | 90 | 69.9588 | 38.48989867 | TRUE | FALSE

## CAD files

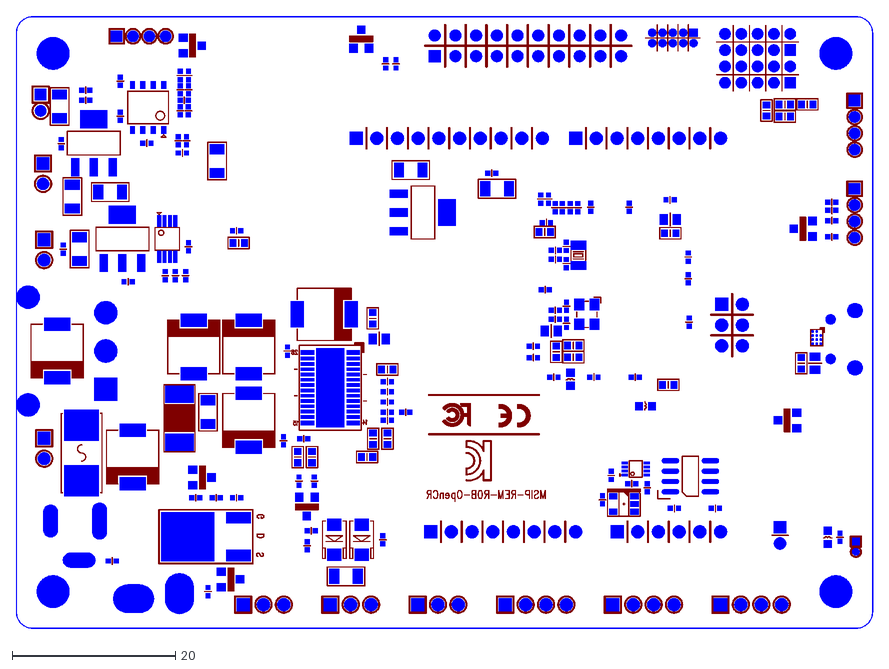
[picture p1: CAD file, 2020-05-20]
CAD/OpenCR_REVH_DXF_Bottom.dxf
105.1 x 75.1

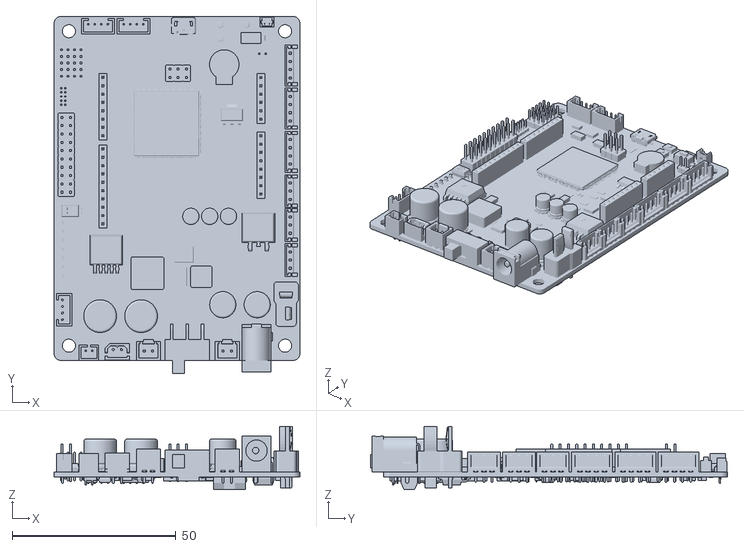
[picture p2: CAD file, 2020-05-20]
Layout/OpenCR_REVH.stl
75.0 x 109.0 x 19.4

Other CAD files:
Layout/OpenCR_REVH.dwg

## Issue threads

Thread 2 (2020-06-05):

DXL Power

dabenpb, 2020-06-05:
I would have suspected that the DXL power would be regulated to 12V but it appears to be whatever is on the SMPS.  Is that what you intend?

ROBOTIS-Will, 2020-10-19:
Please keep track on the thread below.
https://github.com/ROBOTIS-GIT/OpenCR/issues/251
I'll close this as it is a duplicated issue.
Thank you.

dabenpb, 2020-10-19:
Thanks.

Closed 2020-10-19.

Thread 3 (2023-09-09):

Deans-T connector footprint issue

vishrut94, 2023-09-09:

Closed 2025-01-13.

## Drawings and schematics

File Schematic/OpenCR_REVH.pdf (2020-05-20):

PA0-WKUP 34 PA1 35 PA2 36 PA3 37 PA4 40 PA5 41 PA6 42 PA7 43 PA8 100 PA9 101 PA10 102 PA11 103 PA12 104 PA13 105 PA14 109 PA15 110 PB0 46 PB1 47 PB2 48 PB3 133 PB4 134 PB5 135 PB6 136 PB7 137 PB8 139 PB9 140 PB10 69 PB11 70 PB12 73 PB13 74 PB14 75 PB15 76 PC14-OSC32_IN 8 PC15-OSC32_OUT 9 PH0-OSC_IN 23 PH1-OSC_OUT 24 NRST 25 BOOT0 138 PDR_ON 143
PD0 114 PD1 115 PD2 116 PD3 117 PD4 118 PD5 119 PD6 122 PD7 123 PD8 77 PD9 78 PD10 79 PD11 80 PD12 81 PD13 82 PD14 85 PD15 86 PE0 141 PE1 142 PE2 1 PE3 2 PE4 3 PE5 4 PE6 5 PE7 58 PE8 59 PE9 60 PE10 63 PE11 64 PE12 65 PE13 66 PE14 67 PE15 68 PF0 10 PF1 11 PF2 12 PF3 13 PF4 14 PF5 15 PF6 18 PF7 19 PF8 20 PF9 21 PF10 22 PF11 49 PF12 50 PF13 53 PF14 54 PF15 55

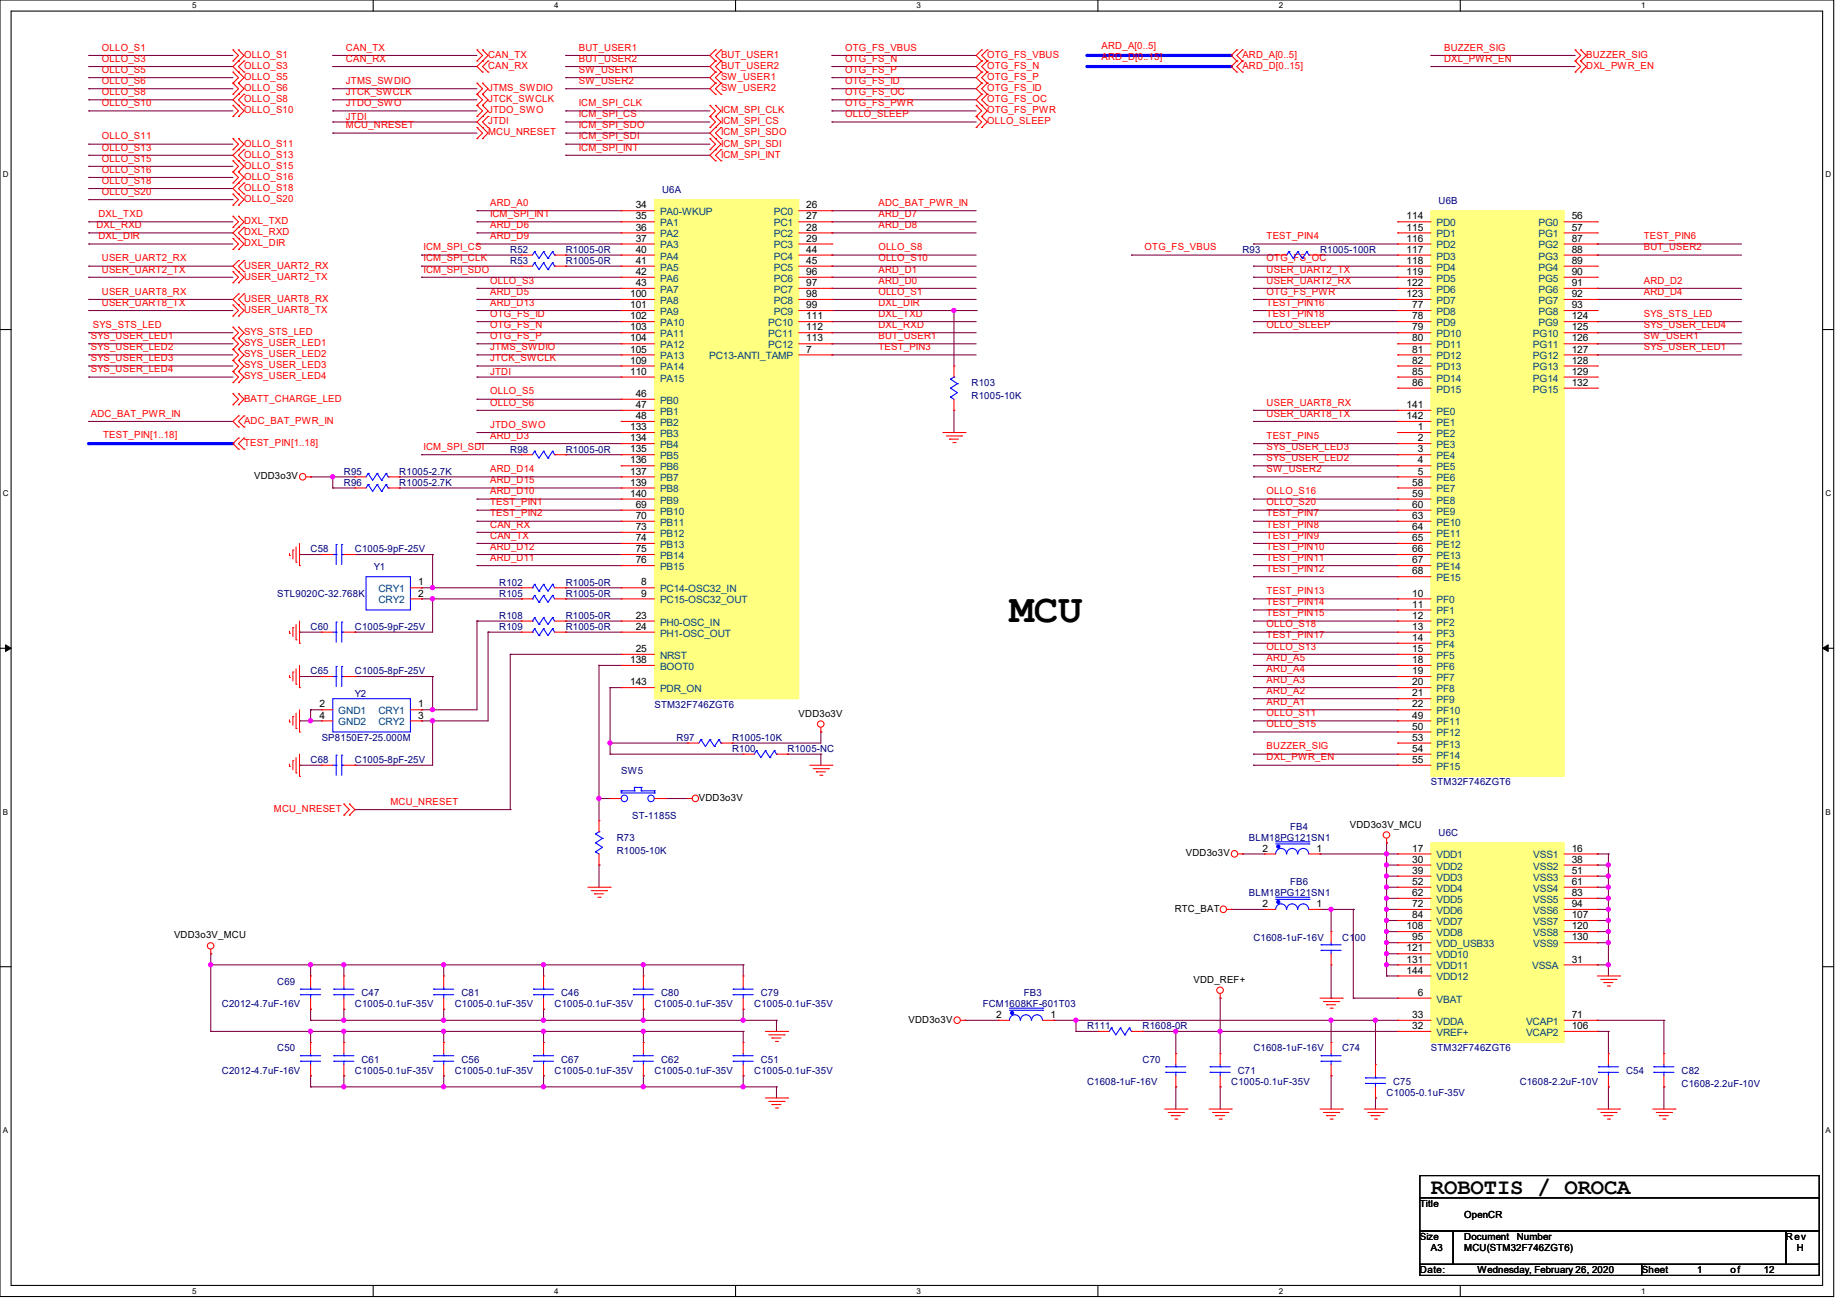
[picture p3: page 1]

# ARDUINO UNO

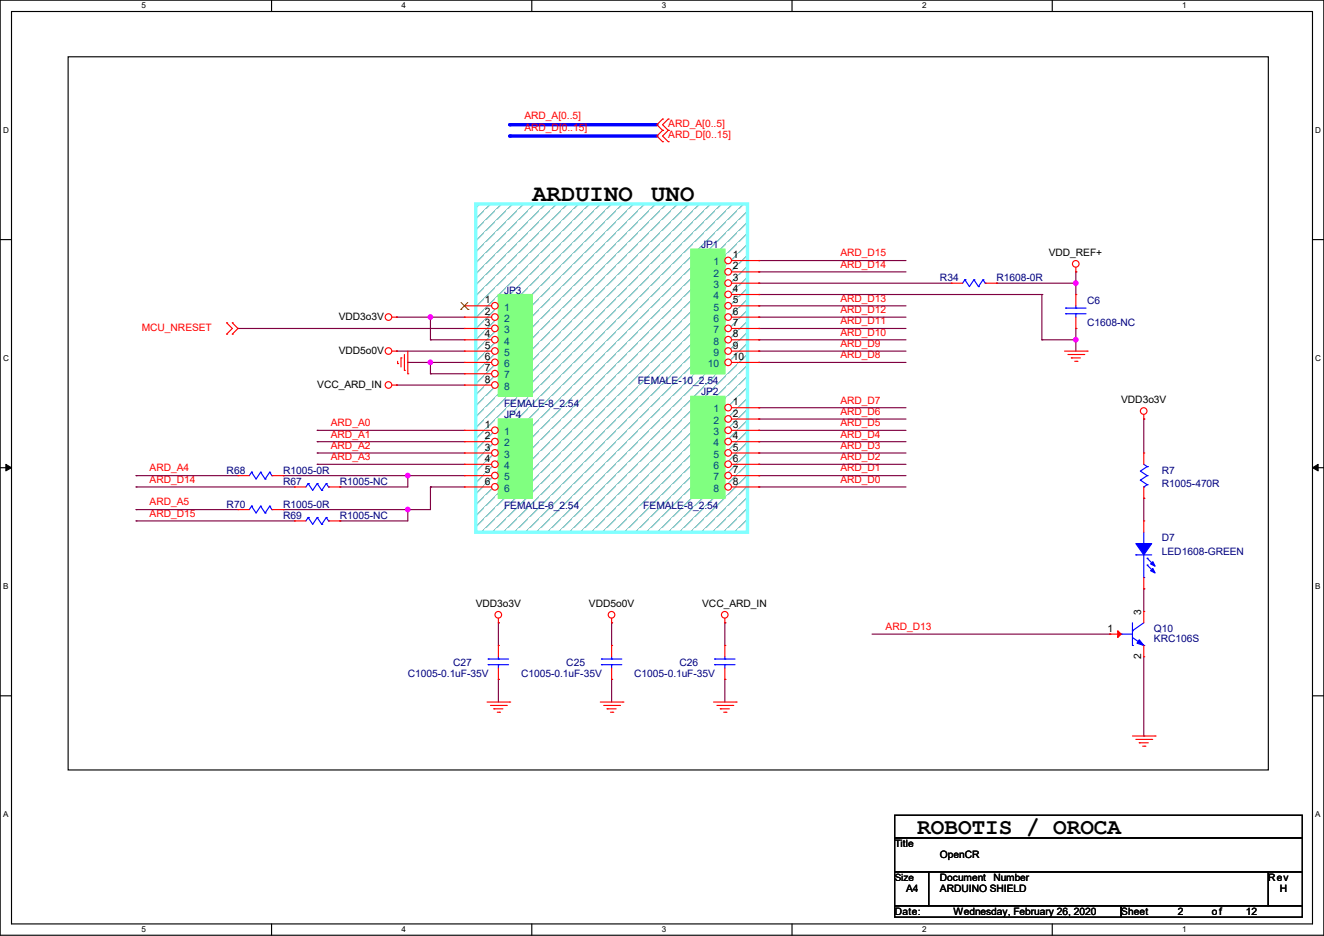
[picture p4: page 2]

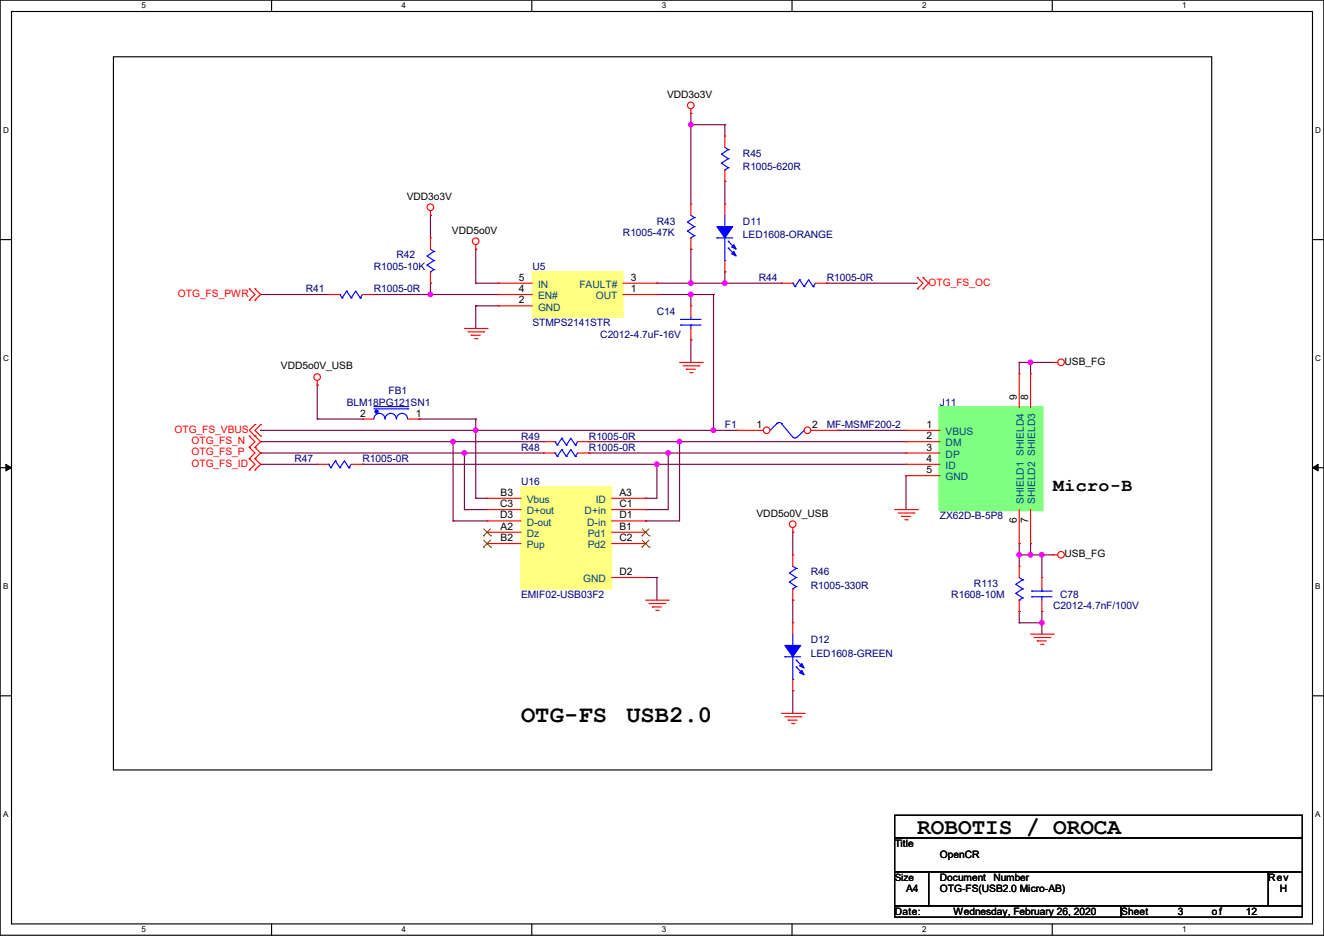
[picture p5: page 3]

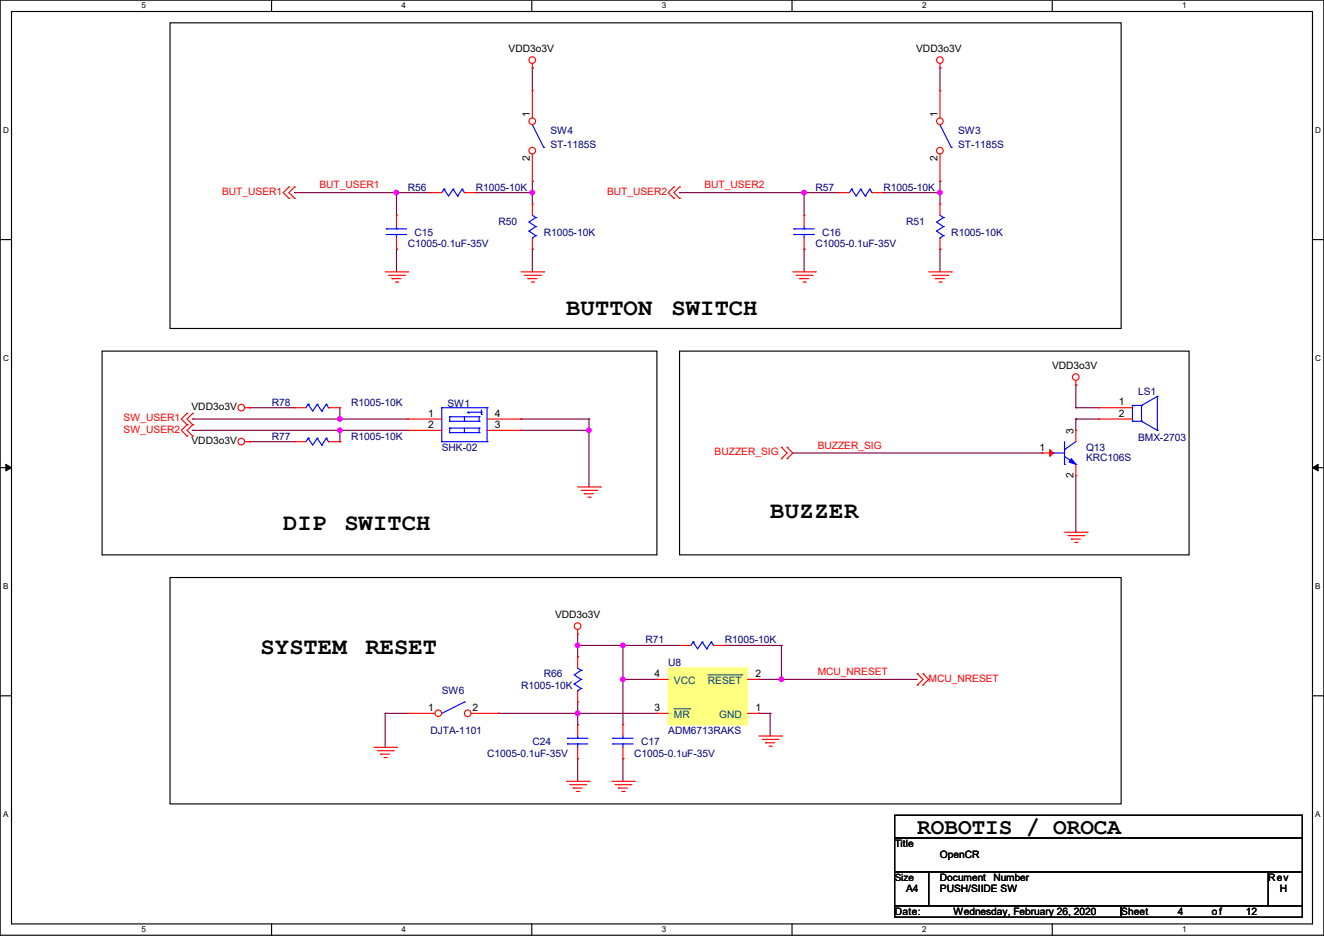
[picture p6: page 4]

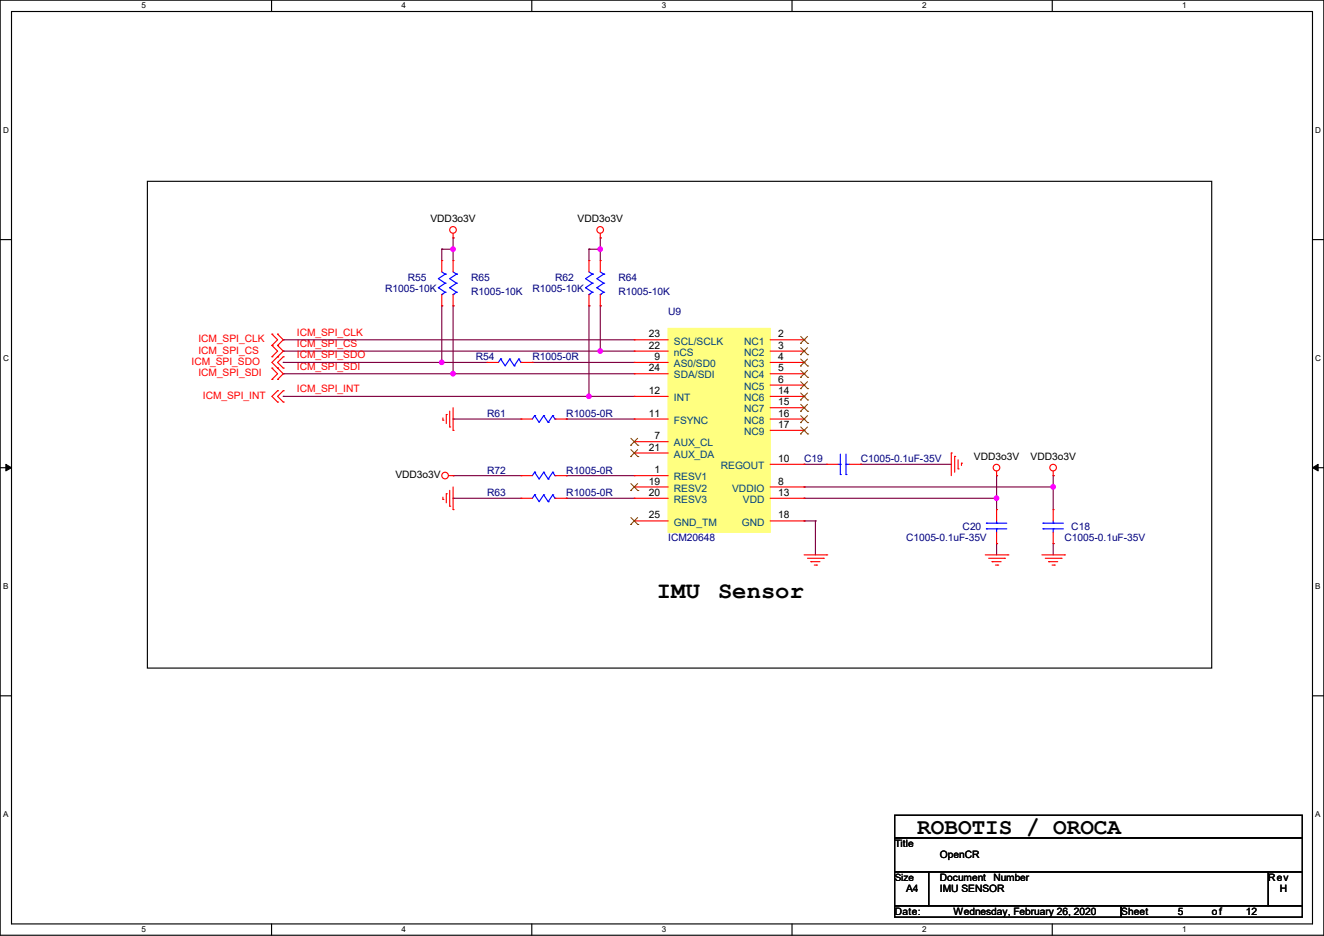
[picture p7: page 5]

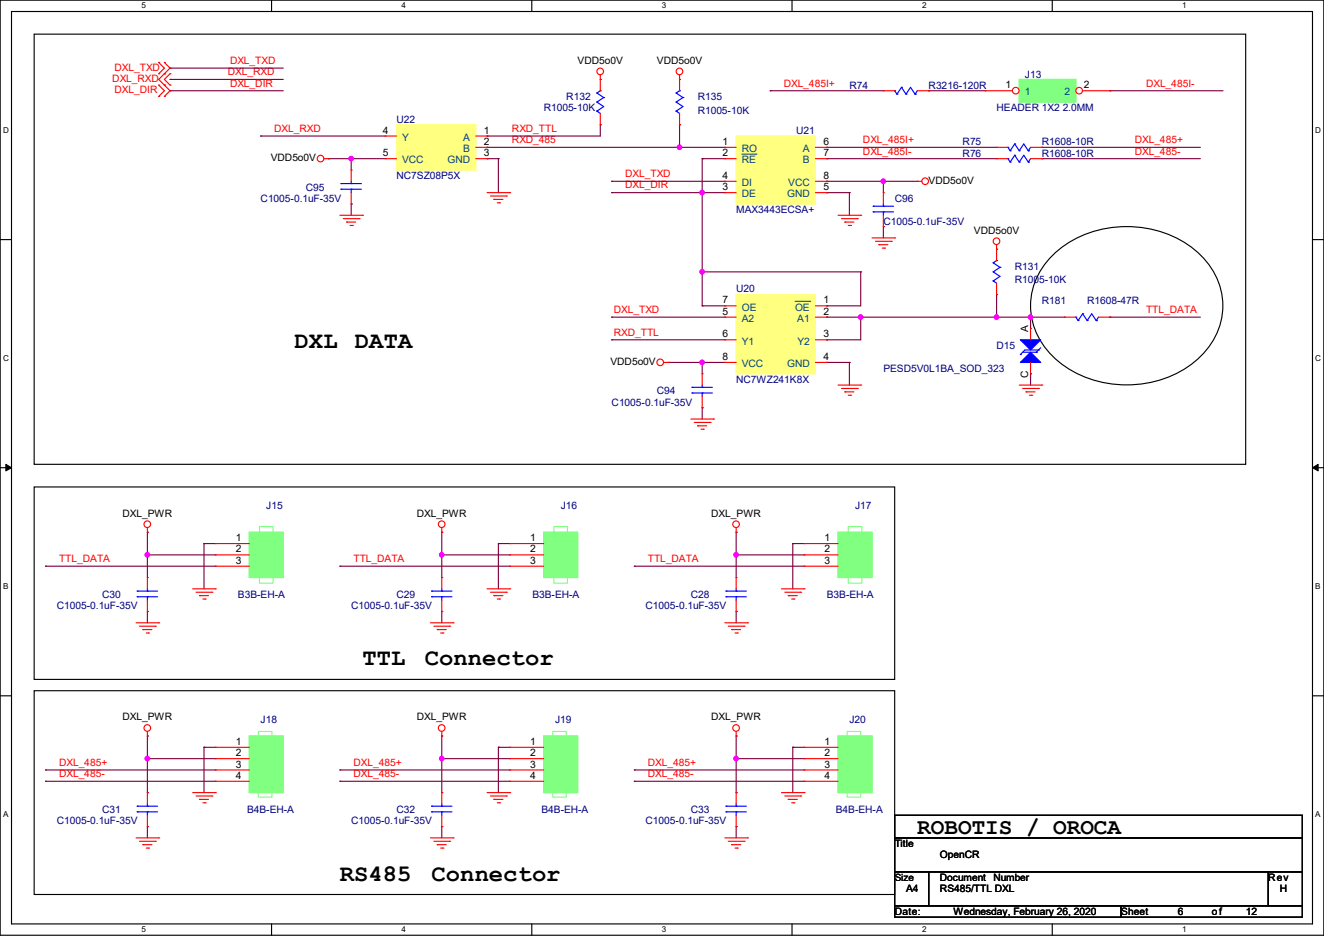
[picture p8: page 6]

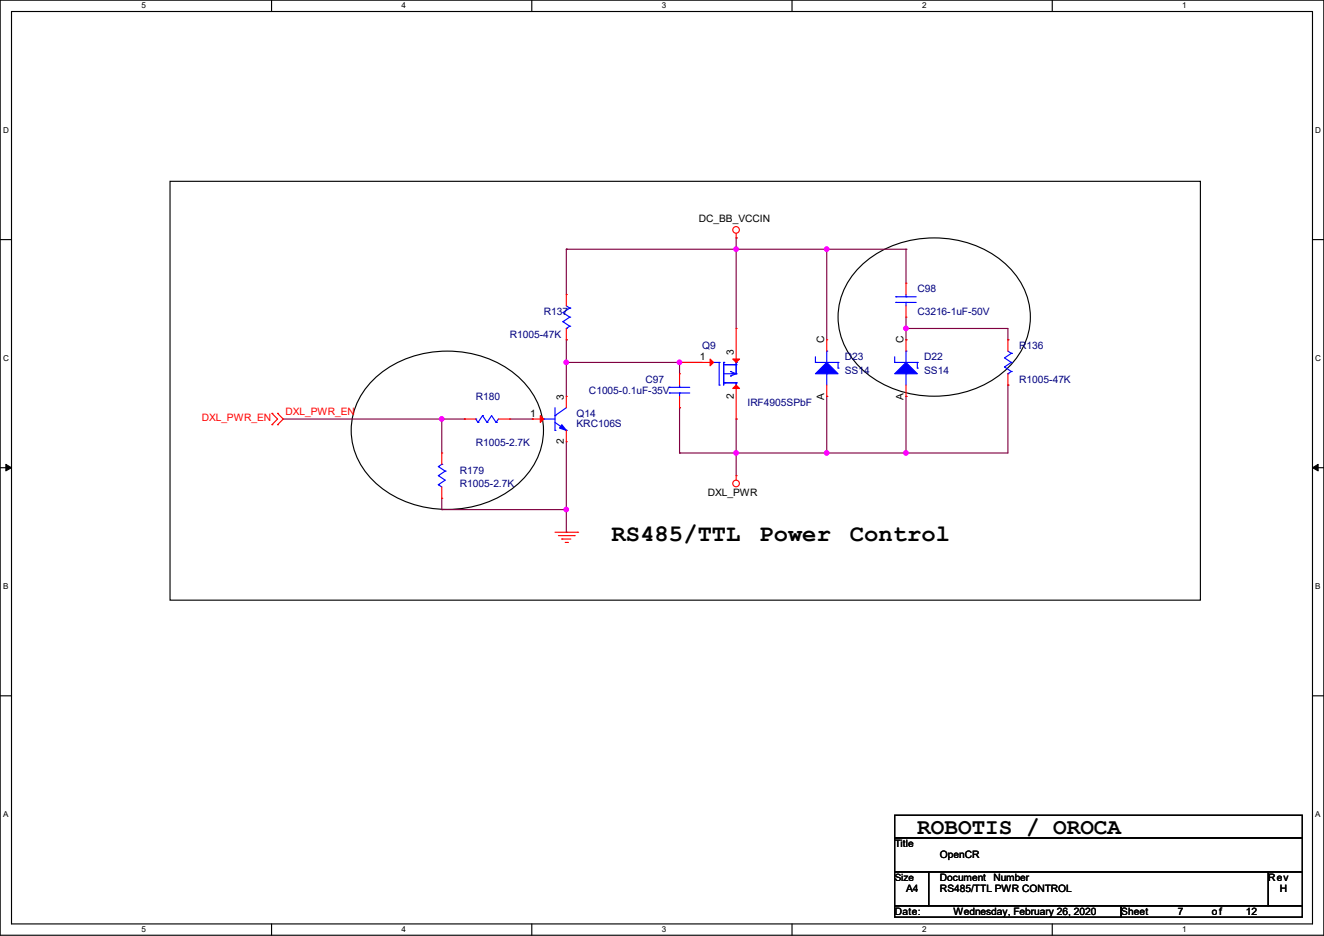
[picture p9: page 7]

# CAN

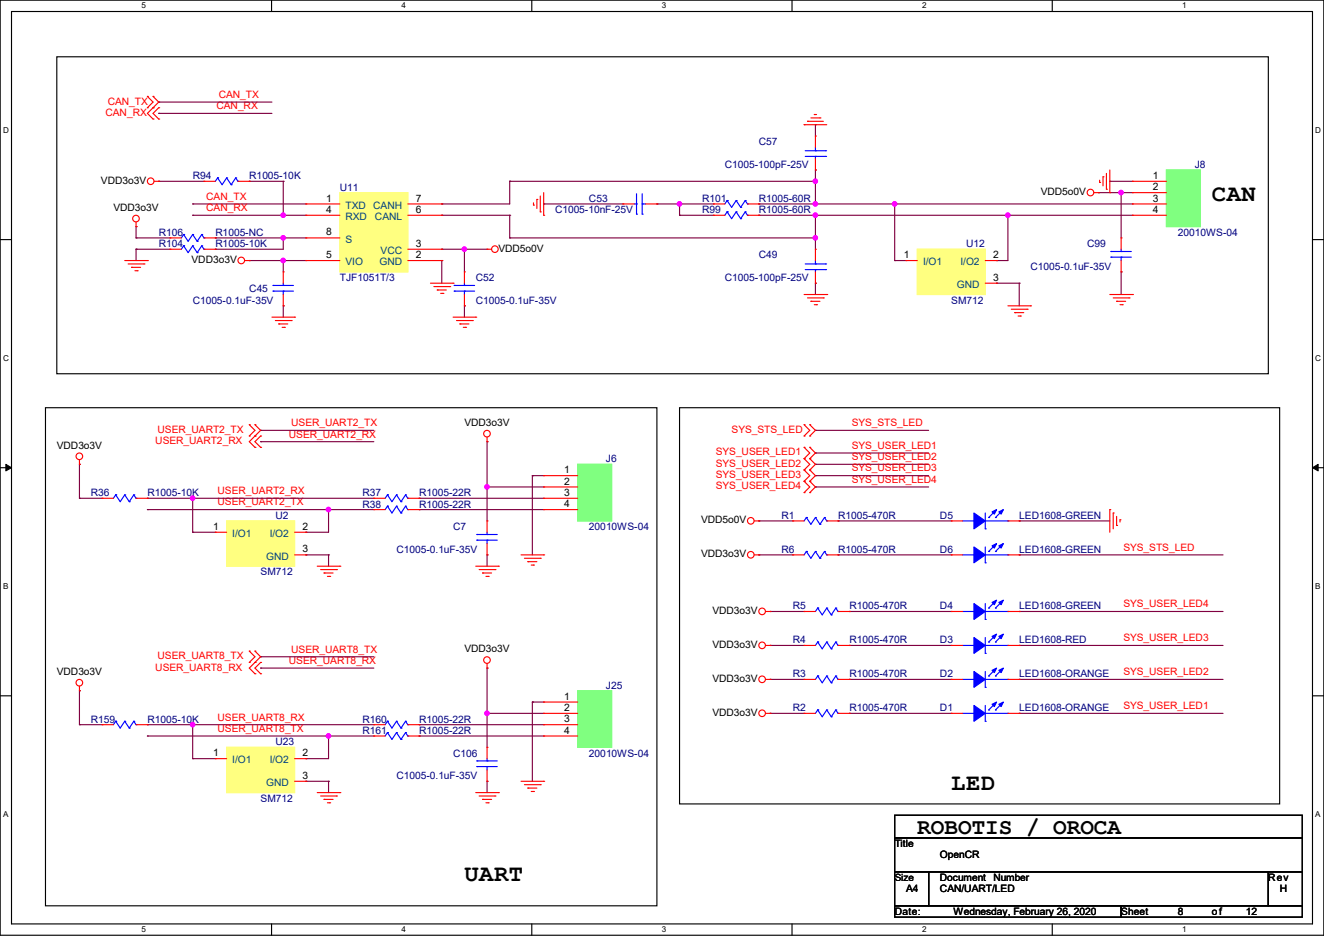
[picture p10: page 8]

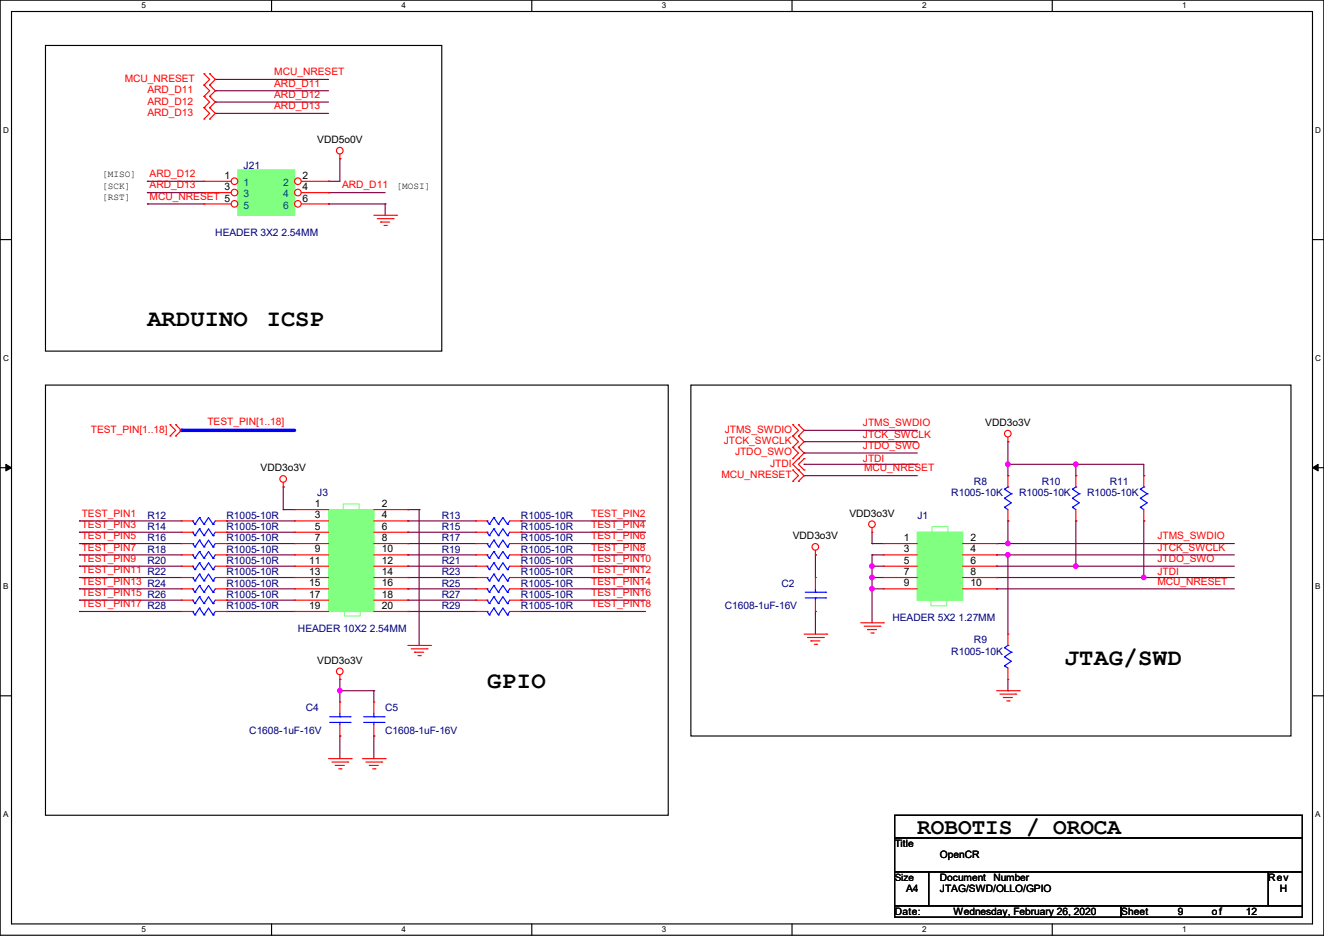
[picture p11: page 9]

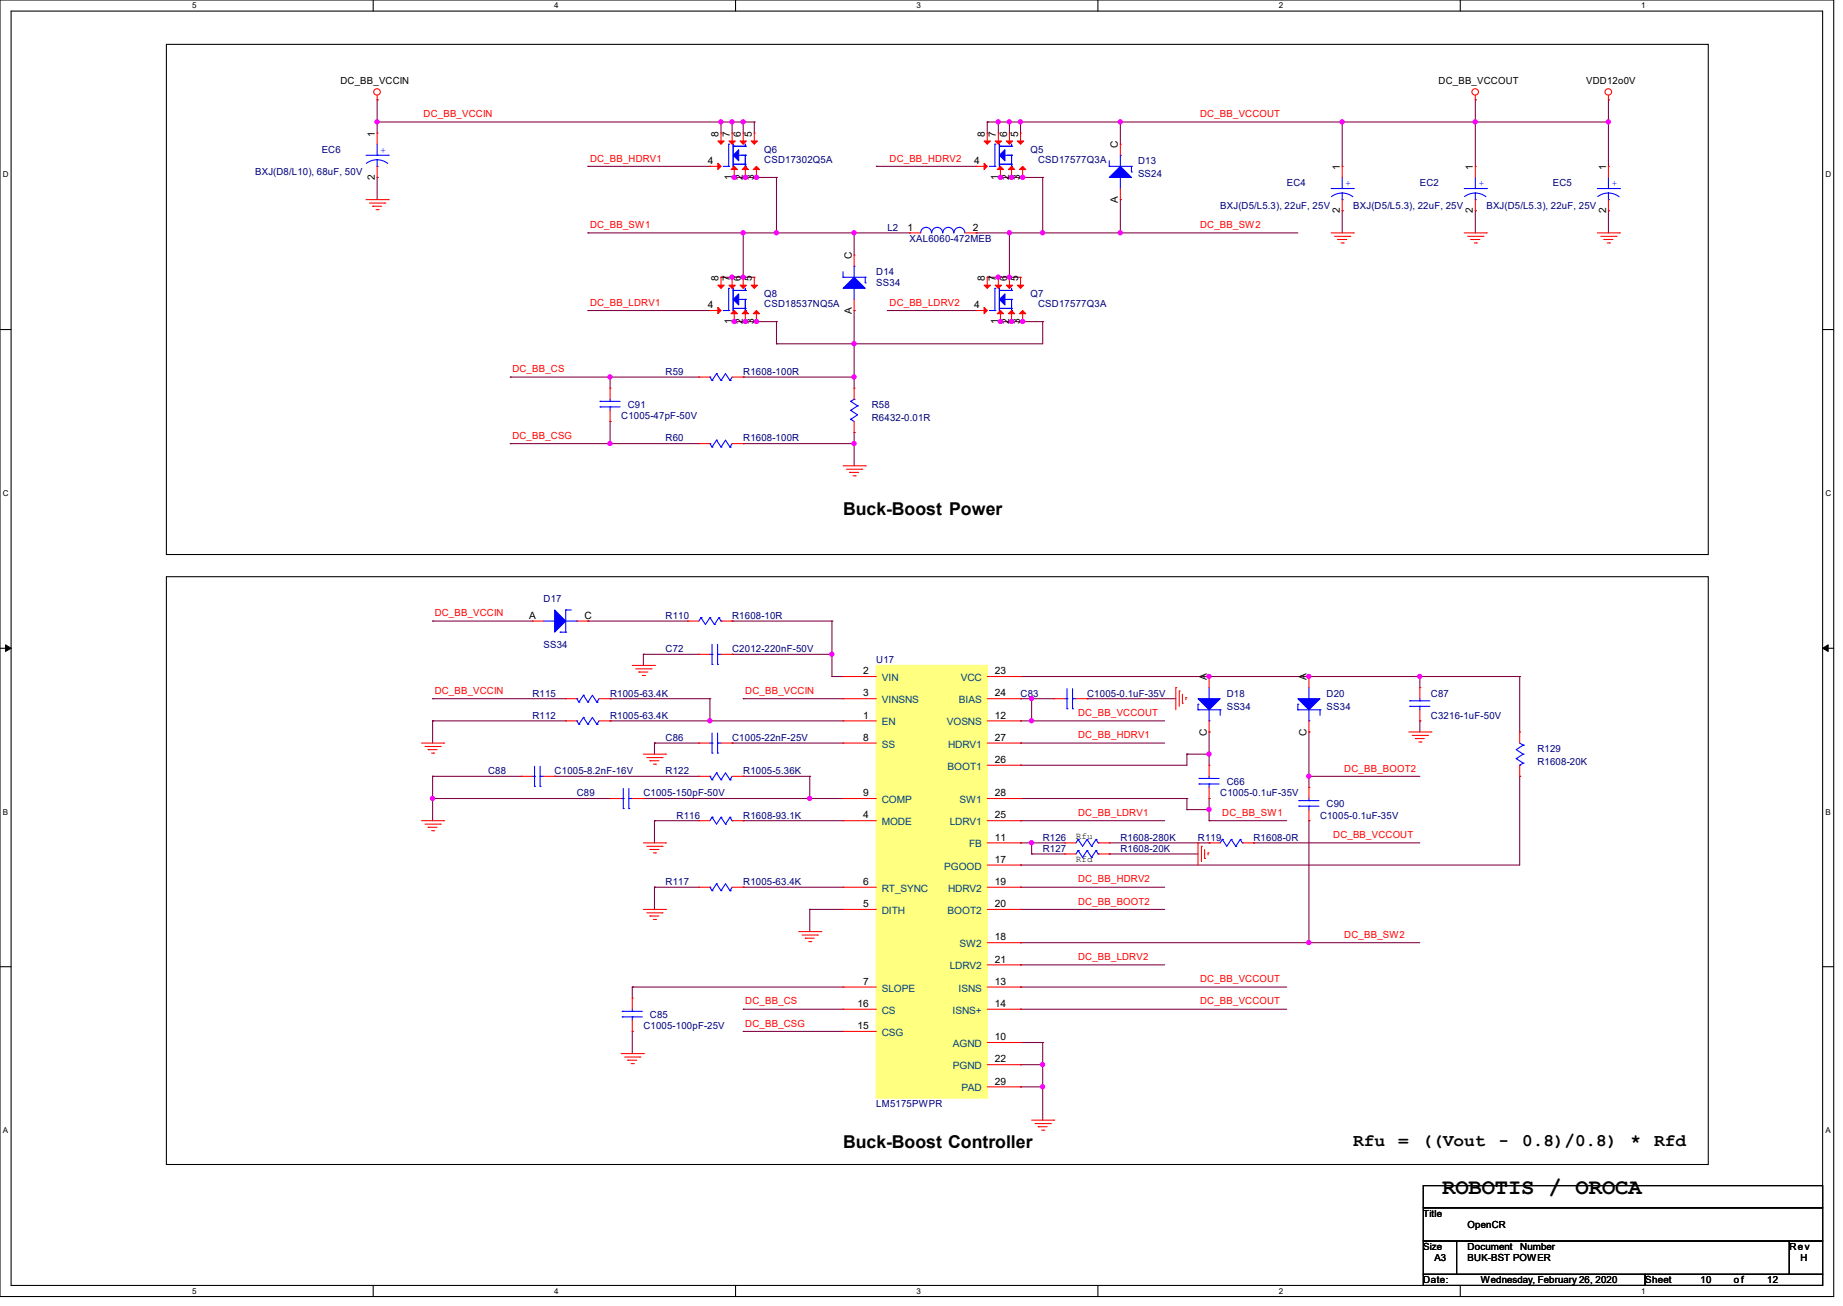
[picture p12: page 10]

### System 5V Out

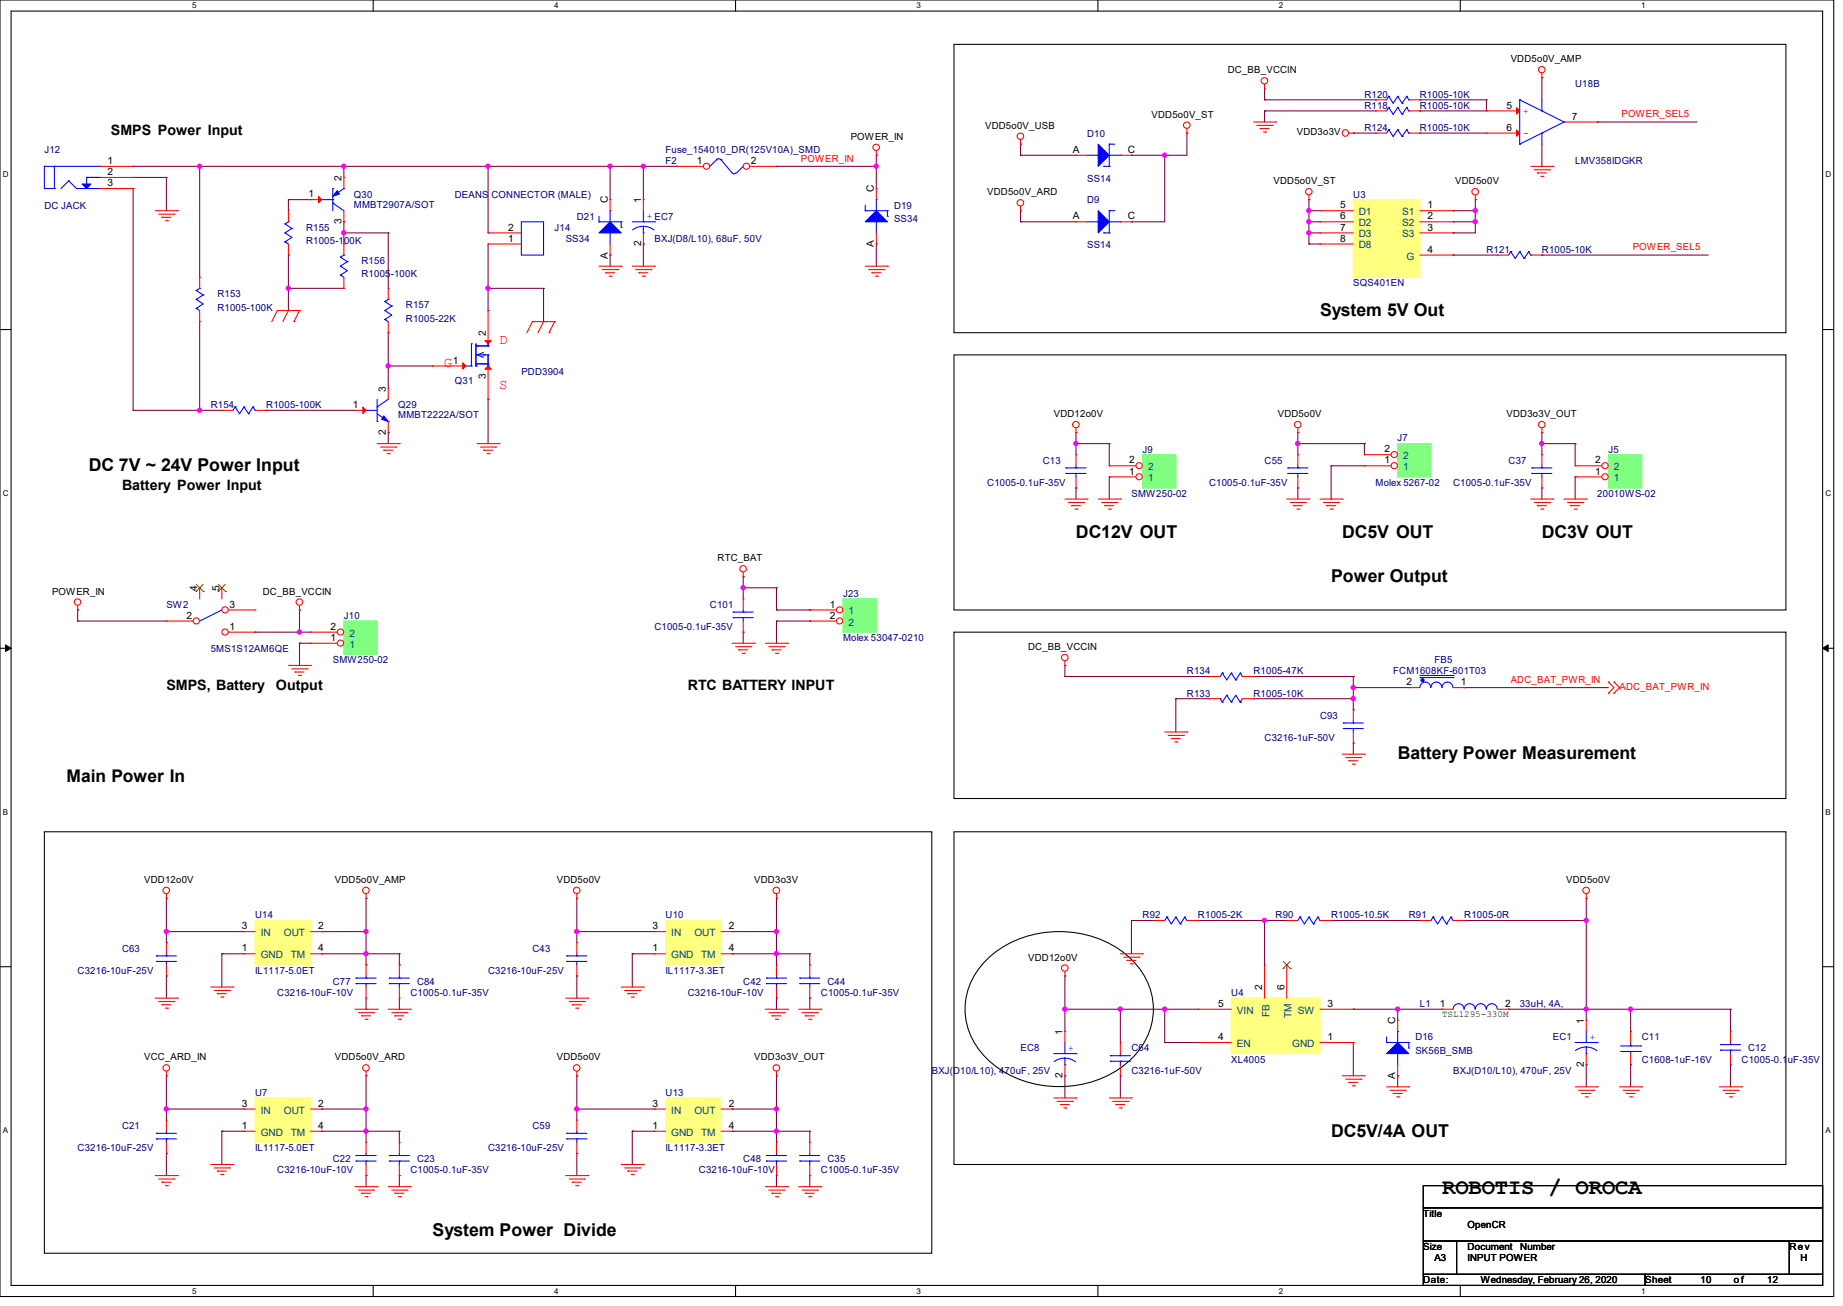
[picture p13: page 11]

2 GND 1 VIN 5 EN 4 TM

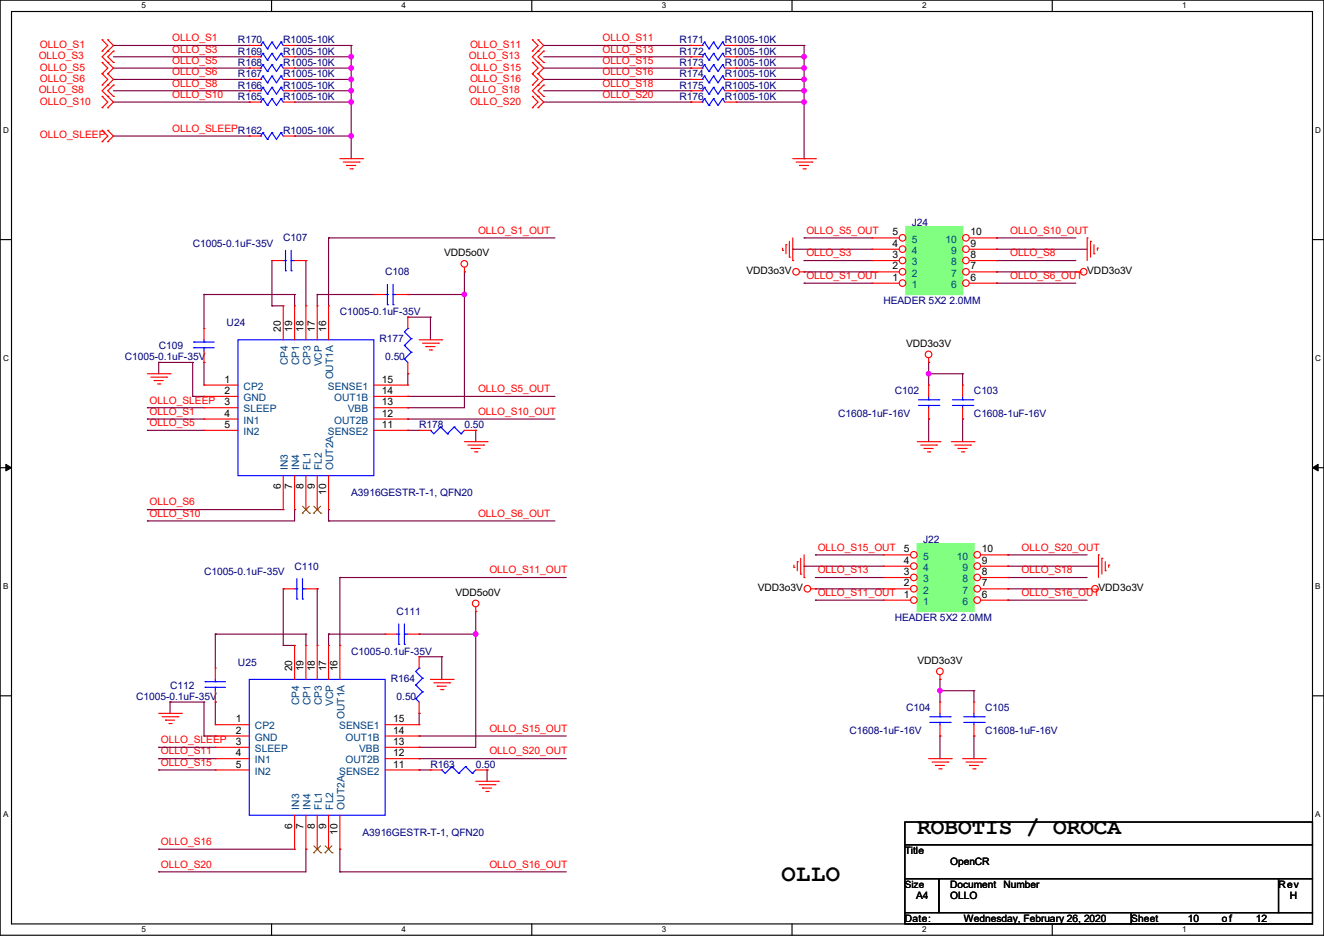
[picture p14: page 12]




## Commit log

2017-04-14 added RevF hardware files.
    [OpenCR_REVF.dwg, OpenCR_REVF_BOM.xls, OpenCR_REVF_DXF_Bottom.dxf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]
2020-05-20 Update RevH
    [OPENCR_REVH.DSN, OpenCR_REVF.dwg, OpenCR_REVF_BOM.xls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]
